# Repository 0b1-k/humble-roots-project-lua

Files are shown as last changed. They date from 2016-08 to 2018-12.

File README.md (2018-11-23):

**Summary**

The Humble Roots Project is a grow room automation control system designed for stable non-stop operation. It is managed through a single configuration file and can communicate with an administrator over SMS text messages. Data visualization is provided in the form of Grafana dashboards powered by InfluxDB.

**Dependencies**

Any platform capable of running Lua + sockets + file system support. Tested under Ubuntu 16, 17, 18+ and Raspbian.

***CMake***

```
sudo apt-get install cmake build-essential
```

***Git***

```
sudo apt-get install git
```

***LuaDist***

Install [LuaDist](http://luadist.org/) in the home folder.

***Humble Roots Project***

```
cd ~
git clone https://github.com/fabienroyer/humble-roots-project-lua.git
cd humble-roots-project-lua
cp -R * ~/LuaDist/share

# Compile the Serial Communication Library
cd ~/LuaDist/share/lua-serial
make

# Copy the library to the project folder. For 32-bit platforms:
cp ./build/lin32/libserial.so ~/LuaDist/share/weed
# or 64-bit platforms
cp ./build/lin64/libserial.so ~/LuaDist/share/weed

# Compile the SMS PDU encoding / decoding library
cd ~/LuaDist/share/smspdu
make

# Copy the library to the project folder. For 32-bit platforms
cp ./build/lin32/smspdu.so ~/LuaDist/share/weed
# or 64-bit platforms
cp ./build/lin64/smspdu.so ~/LuaDist/share/weed

# Copy the template config file to a usable .toml config file
cd ~/LuaDist/share/weed/config
mv config.tpl config.toml
cd ..
# Start the project
./../../bin/lua control.lua
```

On startup, the project will show a console output like this:

```
[TRACE 14:15:30] ./replay.lua:14: Replay data lines: 713
[INFO  14:15:30] control.lua:178: The Humble Roots Project
[INFO  14:15:30] control.lua:179: 
			                  |
			                 |.|
			                 |.|
			                |\./|
			                |\./|
			.               |\./|               .
			 \^.\          |\\.//|          /.^/
			  \--.|\       |\\.//|       /|.--/
			    \--.| \    |\\.//|    / |.--/
			     \---.|\    |\./|    /|.---/
			        \--.|\  |\./|  /|.--/
			           \ .\  |.|  /. /
			 _ -_^_^_^_-  \ \\ // /  -_^_^_^_- _
			   - -/_/_/- ^ ^  |  ^ ^ -\_\_\- -
					  	|

[INFO  14:15:30] control.lua:180: Copyright (c) 2017 Fabien Royer
[INFO  14:15:30] control.lua:185: Gateway started
[INFO  14:15:30] ./listener.lua:17: TCP listener @ ::1:42024
[DEBUG 14:15:31] control.lua:172: Replay node=2&rssi=-43&t=srh&bat=4.77&low=0&pwr=1&p=1
[DEBUG 14:15:32] control.lua:172: Replay node=20&rssi=-31&t=rly&bat=5.00&low=0&pwr=1&r=4&s=1
[DEBUG 14:15:33] control.lua:172: Replay node=20&rssi=-31&t=rly&bat=5.00&low=0&pwr=1&r=5&s=1
[DEBUG 14:15:34] control.lua:172: Replay node=20&rssi=-30&t=rly&bat=5.00&low=0&pwr=1&r=5&s=1
[DEBUG 14:15:35] control.lua:172: Replay node=40&rssi=-44&t=clm&bat=3.78&low=0&pwr=0&tmp=24.58&rh=55
...
```

***InfluxDB***

All sensor data is logged to [influxdb](https://influxdata.com/time-series-platform/influxdb/).
Once influxdb is installed, create a 'sensors' and an 'events' database, then enable influxdb logging in ./config/config.toml. See /weed/config/influxdb-udp.conf for a ready to use config snippet for communicating with InfluxDB over UDP (recommended over HTTP).

***Grafana***

Uses Grafana to plot sensor data. Once Grafana is installed, configure it to use the Influxdb instance previously installed and import the
Humble Roots Project dashboard from ./dashboard/grafana/Lab.json.

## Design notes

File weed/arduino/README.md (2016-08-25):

# Humble Roots Project Sketches

The various Arduino sketches provided as part of the project are intended to run on Moteino boards equipped with HopeRF RFM69W 433MHz transceivers.
The wireless nodes share a network ID but also have their own unique ID on the network.
In addition, the nodes encrypt all transmitted data using [AES-128](https://en.wikipedia.org/wiki/Advanced_Encryption_Standard).
To this end, the nodes must share a 16-byte long private key to be able to communicate with each other.
**By default, that private key is set to "&lt;YourCryptoKey!&gt;" which should be changed before compiling and uploading the sketches to the nodes.**
To do so, open the .ino files under the /arduino folder.
Then, using the 'Find...' (CTRL+F) function in the Arduino IDE, search for the default AES key and replace it with your own 16-byte long key.
Repeat this for each sketch, making sure to save all changes.

## Required Arduino Dependencies

The following libraries must be added to the Arduino IDE in order to compile the project sketches.

* [Si7021 temperature & humidity sensor library](https://github.com/LowPowerLab/SI7021)
* [BMP180 Bosch sensor library](https://github.com/LowPowerLab/SFE_BMP180)
* [RFM69 library for RFM69W and RFM69HW](https://github.com/LowPowerLab/RFM69)
* [Low Power Library for Arduino](https://github.com/LowPowerLab/LowPower)
* [PString text formating library](http://arduiniana.org/libraries/PString/)
* [EEPROMex arduino library](http://playground.arduino.cc/Code/EEPROMex)

# Bill of materials

The Arduino sketches provided with the Humble Root Project are designed to run on the following hardware or equivalent.

## Climate node

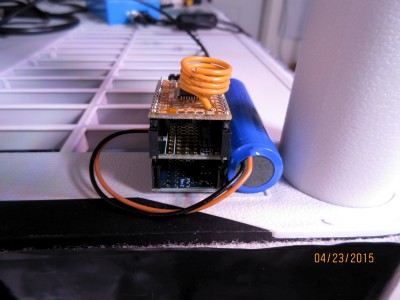
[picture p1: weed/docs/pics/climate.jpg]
Climate node


* 1x [Moteino MCU](https://lowpowerlab.com/shop/index.php?_route_=moteino-r4)
* 1x [Transceiver (RFM69W @ 433MHz)](https://lowpowerlab.com/shop/index.php?_route_=Moteino/RFM69W)
* 1x [Power Shield](https://lowpowerlab.com/shop/index.php?_route_=powershield)
* 1x [WeatherShield](https://lowpowerlab.com/shop/index.php?_route_=weathershield)
* 1x [Lithium Ion Cylindrical Battery - 3.7v 2200mAh](http://www.adafruit.com/products/1781)

## Gateway node

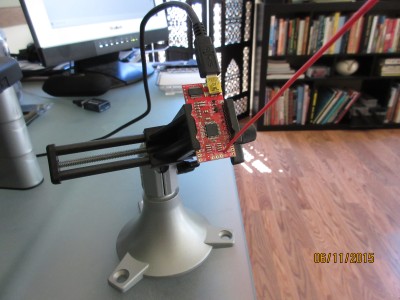
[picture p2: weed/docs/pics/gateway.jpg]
Gateway node


* 1x [Moteino USB MCU](https://lowpowerlab.com/shop/index.php?_route_=Moteino/moteinousb)
* 1x [Transceiver (RFM69W @ 433MHz)](https://lowpowerlab.com/shop/index.php?_route_=Moteino/RFM69W)
* 1x Mini USB cable
* 1x Computer capable of running Python 2.7.x

The Humble Roots Project Python code has been tested on the following systems

* [Ubuntu 14.04 (Desktop)](http://www.ubuntu.com/download/desktop)
* [Raspberry Pi (Debian Wheezy)](https://www.raspberrypi.org/downloads/)
* [BeagleBone Black (Ubuntu)](http://elinux.org/BeagleBoardUbuntu)

## Relay node

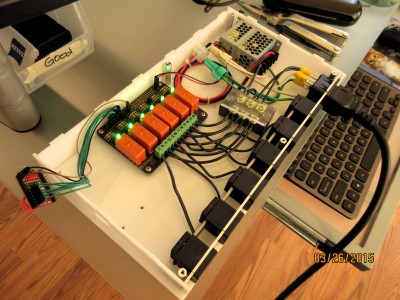
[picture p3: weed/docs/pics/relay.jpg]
Relay node


**Warning: the relay node switches high voltages and currents!**
**You must be comfortable working with high power before attempting to build this node.**
**Please seek help if you are unsure about the safety precautions needed when working with high power.**

* 1x [Moteino MCU](https://lowpowerlab.com/shop/index.php?_route_=moteino-r4)
* 1x [Transceiver (RFM69W @ 433MHz)](https://lowpowerlab.com/shop/index.php?_route_=Moteino/RFM69W)
* 1x [Humble Roots Project Relay Board](../hardware)
* 6x [Schurter AC Power Entry Modules SNAP-IN QC/WIRE NEMA](http://www.mouser.com/ProductDetail/Schurter/43000703/?qs=%2fha2pyFaduhBCtkGZdsCVlhWWizSnRMPw8sJ%2fGTwrMM%3d)
* 1x [Schurter AC Power Entry Modules 1.2mm Snap-In INLET 16A](http://www.mouser.com/ProductDetail/Schurter/47938000/?qs=%2fha2pyFaduhGWt2JM6mVJBsIsAazDcRYIle0WaEJEYg%3d)
* 1x [5V 15W 1 Phase Switching Power Supply](http://www.mouser.com/ProductDetail/Delta-Electronics/PMC-05V015W1AA/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)
* 1x [Schurter AC Power Cord IEC320 16A 2.0m V-Lock](http://www.mouser.com/ProductDetail/Schurter/60512047/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)
* 1x 12 AWG solid core wire spool (black)
* 1x 12 AWG solid core wire spool (green)
* 1x 12 AWG solid core wire spool (white)
* 1x 12 AWG stranded wire spool (black)
* 1x 12-10 AWG 6-Circuit Terminal Block
* 3x Winged Twist Wire Connectors
* 3x 12-10 AWG 0.25 in. Tab Female Fully-Insulated Disconnects
* 1x 24 AWG stranded prototyping wire (red)
* 1x 24 AWG stranded prototyping wire (black)

Note: any relay board with at least 6 channels capable of handling loads ranging from 10A to 16A @ 240V will work.

## Soil Relative Humidity Node

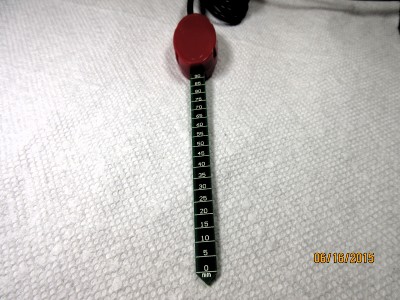
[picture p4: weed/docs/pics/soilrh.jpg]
Soil RH node


* 1x [Moteino MCU](https://lowpowerlab.com/shop/index.php?_route_=moteino-r4)
* 1x [Transceiver (RFM69W @ 433MHz)](https://lowpowerlab.com/shop/index.php?_route_=Moteino/RFM69W)
* 1x [MightyBoost](https://lowpowerlab.com/shop/index.php?_route_=mightyboost)
* 1x [Lithium Ion Battery Pack - 3.7V 6600mAh](http://www.adafruit.com/products/353)
* 1x [VH400 Soil Moisture Sensor Probe](http://www.vegetronix.com/Products/VH400/)

## Valve node

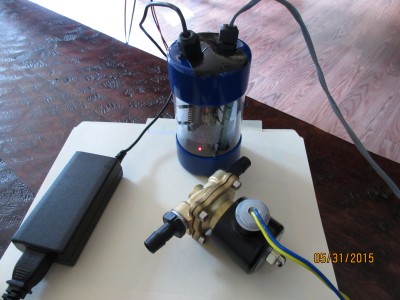
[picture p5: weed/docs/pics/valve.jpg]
Valve node


**Warning: the 'valve' node switches high currents!**
**You must be comfortable working with high power before attempting to build this node.**
**Please seek help if you are unsure about the safety precautions needed when working with high power.**

* 1x [Moteino MCU](https://lowpowerlab.com/shop/index.php?_route_=moteino-r4)
* 1x [Transceiver (RFM69W @ 433MHz)](https://lowpowerlab.com/shop/index.php?_route_=Moteino/RFM69W)
* 1x [Humble Roots Project Solenoid Control Board](../hardware)
* 1x [12V 5A Switching Power Supply](http://www.adafruit.com/product/352)
* 1x [Brass Liquid Solenoid Valve - 12V - 1/2 NPS](http://www.adafruit.com/products/996)
* 1x 18 AWG stranded wire (spool)

## Water Level nodes

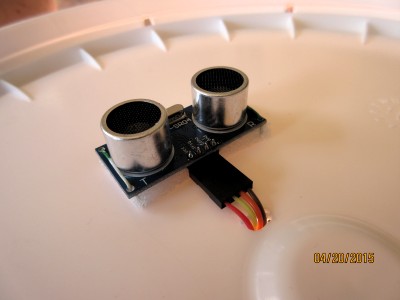
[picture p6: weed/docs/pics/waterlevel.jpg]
Water Level node


Two 'water level' nodes are used as part of the project as share the same code.
However, the network IDs for the two nodes are different and must be edited before compiling and uploading the code.

* A 'sump' node (ID=4)
* A 'tank' node (ID=30)

Start by loading the [waterlevel.ino sketch](./waterlevel/waterlevel.ino) in the Arduino IDE.

Locate the following line, ensuring that the node ID is set to 4.

```
	#define THIS_NODE_ID             4
```

Compile the sketch and upload it to the Moteino node used for the 'sump' node.

Then, set the node ID to 30.

```
	#define THIS_NODE_ID             30
```

Compile the sketch again and upload it to the Moteino node used for the 'tank' node.

* 1x [Moteino MCU](https://lowpowerlab.com/shop/index.php?_route_=moteino-r4)
* 1x [Transceiver (RFM69W @ 433MHz)](https://lowpowerlab.com/shop/index.php?_route_=Moteino/RFM69W)
* 1x [HC-SR04 ultrasonic sensor](https://lowpowerlab.com/shop/index.php?_route_=HC-SR04)
* 1x [SparkFun micro B USB Breakout](https://www.sparkfun.com/products/12035)
* 1x [5V 1A (1000mA) USB port power supply](http://www.adafruit.com/products/501)
* 1x Micro B USB cable

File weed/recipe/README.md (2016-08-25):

Recipe intended to grow Indica plants with a 45 days flowering cycle.

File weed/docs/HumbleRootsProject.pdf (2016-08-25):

# The Humble Roots Project

## Home Automation Applied To Medical Cannabis Cultivation

Author: Fabien Royer (https://www.linkedin.com/in/fabienroyer1967)

Copyright (c) 2015 Fabien Royer (https://www.linkedin.com/in/fabienroyer1967)

Source: https://github.com/fabienroyer/humble-roots

License: Attribution-ShareAlike 4.0 International (CC BY-SA 4.0) (https://creativecommons.org/licenses/by-sa/4.0/)

## Table of Contents

## Introduction

The Humble Roots Project is a grow room automation system designed to meet indoor horticulture challenges using open (http://www.gnu.org/)software, (http://www.gnu.org/) open hardware (https://en.wikipedia.org/wiki/Open-source_hardware) and readily available consumer appliances. The project blends these elements together into an inexpensive, reliable, efficient, automated system, with a focus on sustainability. (https://en.wikipedia.org/?title=Sustainability)
The application of the concepts and technology used as part of the Humble Roots Project is not limited to indoor growing or horticulture; it has far-reaching applications to many other automation scenarios where sensors, actuators, rules and data visualization are combined to solve a problem.

## Inspiration

In 2013, the Humble Roots Project was born out of a need to grow medical cannabis indoors legally, (http://www.doh.wa.gov/ForPublicHealthandHealthcareProviders/HealthcareProfessionsandFacilities/MedicalMarijuanaCannabis) using sustainable, organic, pesticide-free (http://agr.wa.gov/FP/Pubs/docs/398-WSDACriteriaForPesticideUseOnMarijuana.pdf) cultivation methods capable of producing consistent yields, in both quality and quantity.
Medical cannabis patients and caretakers who have determined that investing in their own garden is financially sound and healthy still face several challenges: cannabis can be tricky to grow, (http://www.seattletimes.com/seattle-news/for-pot-yield-of-growersrsquo-dreams-fickle-plants-need-constant-care/) requires constant care and a well-controlled climate (http://blogs.seattletimes.com/pot/2014/08/18/from-seed-to-sale-challenges-abound-for-licensed-pot-growers/) in order to thrive.
While commercial greenhouse automation controllers are well-suited for this task, they're also expensive, proprietary, closed source solutions. Small scale growers typically resort to using 'low-tech' or 'no tech' solutions (i.e lights and irrigation on timers, climate control using a basic thermostat and humidistat) at the risk of losing entire crops. (http://www.growweedeasy.com/7-step-remedy)
The Humble Roots Project was built to fill the gap between commercially available automation systems and low-tech solutions. By automating the control of key processes, and by following some basic best practices, the Humble Roots Project empowers gardeners with the knowledge and the tools needed to reduce certain classes of risks, to minimize manual labor and to conserve precious resources, such as water and power.
To mitigate the steep learning curve associated with cannabis cultivation, the Humble Roots Project aims to provide recipes for growing different types of plants. A recipe is a complete plan for managing the growth cycle of a plant from seed/clone to harvest, including variables such as watering and feeding schedules, lighting schedule, temperature and humidity control, among others. The recipes are meant to educate and guide the budding gardener, as well as allowing a master grower to experiment with and fine-tune the quality and consistency of her yields.

## Indoor Growing Basics

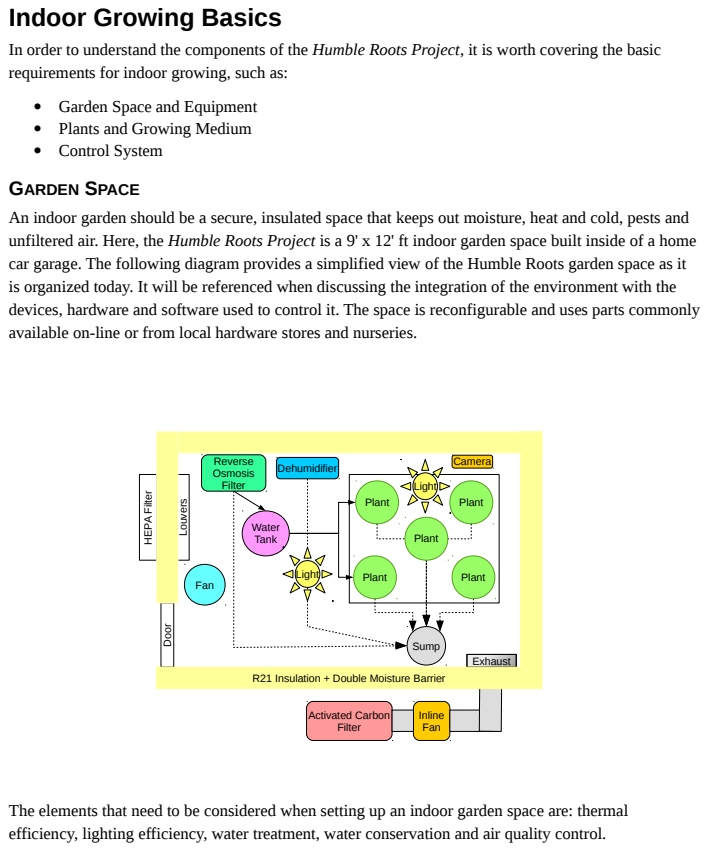
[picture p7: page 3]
Door; HEPA Filter; Louvers; Activated Carbon Filter; Inline Fan; Exhaust; Plant; Sump; Water Tank; Reverse Osmosis Filter; Fan; Light; Dehumidifier

In order to understand the components of the Humble Roots Project, it is worth covering the basic
requirements for indoor growing, such as:
• Garden Space and Equipment
• Plants and Growing Medium
• Control System

GARDEN SPACE
An indoor garden should be a secure, insulated space that keeps out moisture, heat and cold, pests and
unfiltered air. Here, the Humble Roots Project is a 9' x 12' ft indoor garden space built inside of a home
car garage. The following diagram provides a simplified view of the Humble Roots garden space as it
is organized today. It will be referenced when discussing the integration of the environment with the
devices, hardware and software used to control it. The space is reconfigurable and uses parts commonly
available on-line or from local hardware stores and nurseries.

R21 insulation & double moisture barriers

Camera

R21 Insulation + Double Moisture Barrier

The elements that need to be considered when setting up an indoor garden space are: thermal
efficiency, lighting efficiency, water treatment, water conservation and air quality control.

Thermal Efficiency
When designing an indoor garden, it is important to make sure the room

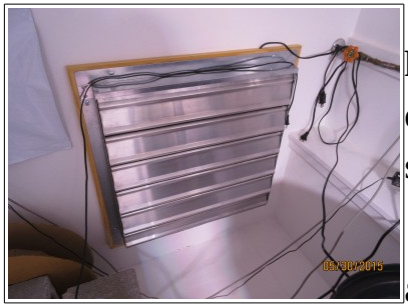
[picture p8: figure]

has high thermal efficiency. Thermal efficiency is important because it has a direct impact on the resources dedicated to heating and cooling the garden space.
For the Humble Roots Project, the garden is located in a room elevated above ground to prevent the floor from getting too cold during the winter months. The floor, the walls and the ceiling are filled with R21 insulation material. (http://energy.gov/energysaver/articles/tips-insulation) The insulated material is sandwiched between two plastic moisture barriers. The door is made of metal, can be locked and seals tightly with its frame.
Because the room is well insulated, it allows for semi-passive cooling and saves a great deal of energy in the process since an air conditioning unit is not required.
Passive cooling relies on a temperature differential between cool outside air and warm air inside of the room. A fan draws cool air inside the room while exhausting warm air.
Running the system at night, when lights are on, ensures that the temperature difference between the two zones is adequate for passive cooling. It also makes operating the garden cheaper since the cost of grid power drops dramatically during off-peak hours.
Louvers automatically lift when air enters the space and shut themselves off afterward, preventing light, air and smells from leaking in or out of the garden. This makes the room ideal for growing and curing cannabis after harvesting. We will see later how software contributes to achieving a climate equilibrium and further contributes to saving energy.

Lighting Efficiency
The largest power consumer in an indoor garden is the lighting. For that

reason, it is important to ensure that it is as efficient as possible: as much light as possible needs to be usable by the plants while keeping the amount of heat produced by the light down to a minimum.
The Humble Roots Project uses two LED lamps, totaling 885 Watts, to illuminate the ~4.5' x 4.5' planted area from above and from one side. The room is painted flat white, from floor to ceiling, making for a very bright environment, maximizing the lamps' output.
LED lights were chosen for their efficiency: they're engineered to only emit light in the blue, red, IR and Ultraviolet (A) parts of the spectrum, which plants thrive on. Nearly all of the green portion of the spectrum is eliminated as it is useless for photosynthesis and therefore, saves energy. These lamps produce little heat, which makes passive cooling possible.
The power of the lamps is sufficient to penetrate through canopy foliage and promotes heavier growth even in the lower parts of the plants.
Finally, LED lamps do not require electronic ballasts, further reducing heat, wiring complexity and potential failure points. Efficiency and reduced part count both help offset the higher cost of LED lamps compared to other lamp types.

Water Treatment and Conservation
Water management in an indoor garden is often the most problematic

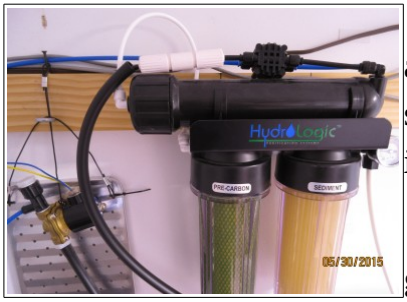
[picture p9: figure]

aspect that needs to be addressed: first, cannabis plants are particularly sensitive to water quality. Second, managing water indoors can be a labor intensive task if there's no infrastructure in place to ease the process.
In the Humble Roots Project, a copper pipe brings cold city water into the garden space. Another PVC pipe leading to the sewers is used to drain out the gray water out of a sump.
City water quality varies greatly depending on where you live but even good quality city water invariably contains additives, such as Chlorine or Chloramine (http://en.wikipedia.org/wiki/Chloramine) as well as other minerals that will negatively impact cannabis plants. If left unfiltered, these minerals and metals can lead to toxicity or deficiencies in the plants. Therefore, it is wise to 'scrub' city water with a carbon filter or a reverse-osmosis system before using it in a cannabis garden.

There are efficiency trade-offs to be considered with different water treatment methods: for instance, a reverse-osmosis system produces some 'waste water' and carbon filters eventually need to be replaced.
While Chlorine just evaporates when left to air out for a few days, Chloramine takes much longer to dissipate and that water can be problematic to store in the meantime and can add unwanted humidity to the air.
Carbon filtering and reverse-osmosis have both been used successfully as part of this project. The operation of the reverse-osmosis system is controlled through a solenoid valve and an ultrasonic distance sensor monitoring the water level in a holding tank.
Assuming that water has been properly conditioned, it still must be applied with care: too much water will prevent the root system from accessing oxygen, stunting and eventually killing the plant. Too little water and the plant will starve, dry out and die too. Accurately tracking and maintaining an optimal moisture level in the growing medium is not only beneficial to the plants, it is also beneficial to our drought-stricken environment: by using smart irrigation techniques, one can grow a very healthy patch of plants with less water per day than is required to flush an average toilet just once. A custom irrigation system was built to meet this goal, combining a soil moisture probe buried root-deep in one of the pots with a water distribution 'network' going to each plant. Software determines when to irrigate and how much.

Some growing techniques consume larger amounts of water than others: for instance, growing with a hydroponic system, except Aeroponics, (https://en.wikipedia.org/wiki/Aeroponics) requires far more water than growing in soil, regardless of scale. For this reason, the Humble Roots Project favors soil as its growing medium. A good soil mix retains just the right amount of moisture, is well oxygenated and provides a strong buffer against sudden pH fluctuations. Soil can also be re-used when cared for and amended properly.

The run-off water coming from irrigating the plants, from the reverse-osmosis system and from the dehumidifier drain into a 'sump', made from three 5-gallon buckets linked together. When the water reaches a defined level, as measured by an ultrasonic distance sensor, it is automatically pumped out to the sewers.

Once combined with nutrients, the pH balance of the water is extremely important to test and adjust, regardless of the growing medium: it affects the availability of nutrients (https://planetpermaculture.wordpress.com/2013/07/25/ph-chart-showing-nutrient-availability/) to the plants and the plants' ability to uptake water. This is addressed in the grow recipes driving the automation. It also ensures that the run-off water pumped out to the sewers is as close to being pH neutral and as nutrient-free as possible.

Air Treatment
Maintaining excellent air quality is vital to grow a healthy garden: filtering out contaminants such as spores, pollens, dust, mites, is key to preventing a host of problems that can quickly destroy a crop. For that reason, in the Humble Roots Project, all the air entering the garden is filtered through a MERV 12 (http://en.wikipedia.org/wiki/Minimum_efficiency_reporting_value) box filter.
Similarly, it is also critical to maintain
an optimal range for air temperature,
relative humidity and CO2 levels, as they also impact the growth of the plants and the amount of resin produced by cannabis flowers.
Air temperature within the grow room is controlled by a powerful
in-line fan exhausting hot air through an activated carbon filter,
scrubbing the air and removing odors in the process. Note that the
filter is mounted outside of the room: this is slightly less efficient than mounting the carbon filter on the inside, but the gain in space is worth the small efficiency trade-off in this case.

A constant air flow is maintained within the room, thanks to a fan circulating

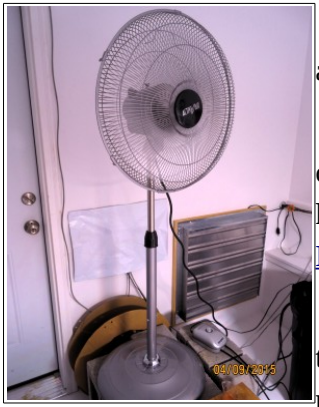
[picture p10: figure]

air around the plants.
The relative humidity within the room is
controlled through a small dehumidifier unit,
keeping molds, such as Powdery Mildew (http://en.wikipedia.org/wiki/Powdery_mildew) and Botrytis, (http://edrosenthal.com/2012/08/ask-ed-marijuana-grow-tip-44-the-botrytis-solution.html) from being able to develop. Controlling air moisture levels also improves

the performance of the activated carbon filter by
preventing carbon particles from 'clumping'
together when excessively humid air passes through it. It's worth mentioning that relative humidity sensors built into consumer-

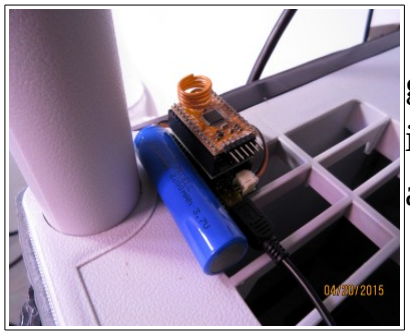
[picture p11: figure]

grade appliances often lack in accuracy. The Humble Roots Project takes this issue into account by using precise sensors so that inexpensive consumer appliances can be controlled accurately.

PLANTS AND GROWING MEDIUM
To make the most of the light available to them, each plant is potted in

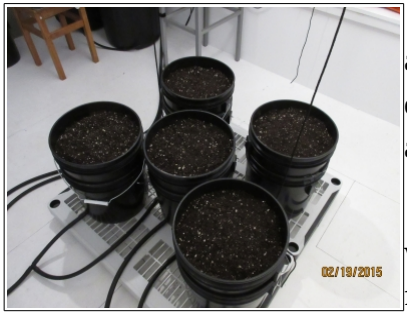
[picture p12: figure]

a 3.5 gallon bucket, allowing for a healthy root system and foliage to develop but not so large that competition for light resources becomes an issue.
A screen mesh helps with training the plants to grow uniformly wherever light is available and helps support the stems during the flowering phase of the growth. The 'planter buckets' are inserted in water collection buckets, all leading to a sump through gravity and flexible tubing.

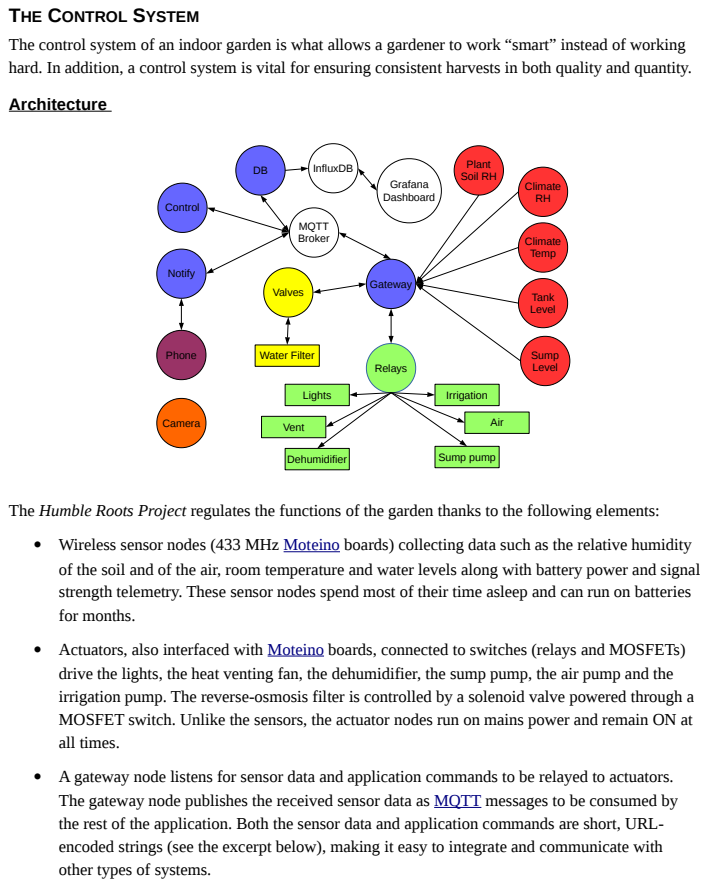
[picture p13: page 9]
Architecture; MQTT Broker; Control; Notify; Gateway; Plant Soil RH; Sump Level; Camera; Relays; Tank Level; Climate RH; Climate Temp; InfluxDB; Grafana Dashboard; Lights; Vent; Dehumidifier; Sump pump; Air; Irrigation; Phone; Valves; Water Filter

THE CONTROL SYSTEM
The control system of an indoor garden is what allows a gardener to work “smart” instead of working
hard. In addition, a control system is vital for ensuring consistent harvests in both quality and quantity.

The Humble Roots Project regulates the functions of the garden thanks to the following elements:
• Wireless sensor nodes (433 MHz Moteino (https://lowpowerlab.com/shop/index.php?_route_=Moteino) boards) collecting data such as the relative humidity
of the soil and of the air, room temperature and water levels along with battery power and signal
strength telemetry. These sensor nodes spend most of their time asleep and can run on batteries
for months.
• Actuators, also interfaced with Moteino (https://lowpowerlab.com/shop/index.php?_route_=Moteino) boards, connected to switches (relays and MOSFETs)
drive the lights, the heat venting fan, the dehumidifier, the sump pump, the air pump and the
irrigation pump. The reverse-osmosis filter is controlled by a solenoid valve powered through a
MOSFET switch. Unlike the sensors, the actuator nodes run on mains power and remain ON at
all times.
• A gateway node listens for sensor data and application commands to be relayed to actuators.
The gateway node publishes the received sensor data as MQTT (http://mqtt.org/) messages to be consumed by
the rest of the application. Both the sensor data and application commands are short, URL-
encoded strings (see the excerpt below), making it easy to integrate and communicate with
other types of systems.

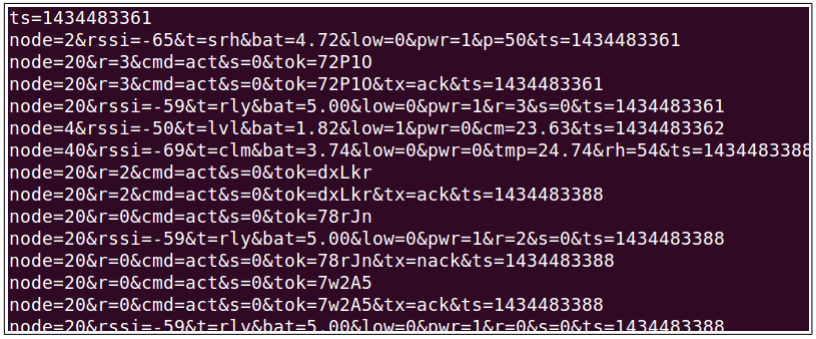
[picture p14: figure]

- Independent application processes (Gateway, DB, Control and Notify) subscribe to sensor data messages and react to them. The Gateway process interfaces with the gateway node over a serial port and therefore, must run on the same physical machine. The other processes can be distributed to separate machines as needed. The DB process writes to a time-series database (InfluxDB) (http://influxdb.com/) feeding Grafana (http://grafana.org/) dashboards; the Control process compares sensor data messages against a user-defined rule set and determines what commands need to be issued to actuators or to other application processes. It also manages time-based rules and configuration changes and last, but not least, executes growth recipes. The Notify process listens for push notifications, (https://www.pushbullet.com/) such as IFTTT commands (https://ifttt.com/recipes) originating from mobile devices. It also pushes notifications back to mobile devices: for instance, Notify can respond to an alert raised by the Control process by sending an SMS message or it can forward a status report whenever requested, among other scenarios. The processes are written in Python (https://www.python.org/) (2.7.x) to maximize portability and will run fine even on a resource-constrained 1st generation Raspberry Pi. (https://www.raspberrypi.org/)
- The Camera process takes pictures of the garden every hour and serves them over HTTP. The hardware used for that purpose is a Raspberry Pi equipped with a camera module, but anything else can be used. The images are meant to observe the impact of recipe changes over time and to produce fun plant growth time lapses. (https://www.youtube.com/watch?v=OL0RneAysnU)

Python, MQTT, Arduino and life at 433 MHz
These technologies were chosen for a simple reason: they're inexpensive, open, well documented and capable of running just about anywhere without being bound to a specific vendor platform: considering the constant stream of development boards coming on the market, it seemed wise for this project to abstract the underlying hardware and the operating system as much as possible. Python, MQTT and Arduino all support this goal.
The choice of using 433 MHz radios from HopeRF deserves a more in-depth explanation: the application doesn't care what the underlying communication link is and from that standpoint, WiFi and Bluetooth would work equally well. For instance, you could mix and match or swap out the Moteino (http://lowpowerlab.com/moteino/) nodes for Particle (https://www.particle.io/) cores, LightBlue (https://punchthrough.com/bean/) beans, AirBoards (http://www.theairboard.cc/) or any other flavor of 'IoT' (http://en.wikipedia.org/wiki/Internet_of_Things) board without the rest of the application knowing about it.

However, in this instance, using HopeRF RFM69x 433 MHz (http://www.hoperf.cn/upload/rf/RFM69-V1.3.pdf) radios had several benefits over the alternatives: because they operate at a lower frequency, these radios work well against obstacles while consuming very little power during transmissions (16mA to 45mA) and can be put to sleep to conserve power. Yet, they maintain a very good range, appropriate for indoor and outdoor applications on our 'homestead'. WiFi alternatives consumed too much power (~150mA) to be viable for extended battery-powered scenarios. Bluetooth Low Energy (http://en.wikipedia.org/wiki/Bluetooth_low_energy) sips power just like the RFM69x radios, but it operates at 2.4 GHz which doesn't work well in point-to-point topologies with no line of sight between transceivers. Since cost was a concern, deploying a mesh network to work around obstacles was out of the question, even though the HopeRF radios can be configured to work in a mesh topology if necessary. ZigBee, (https://en.wikipedia.org/wiki/ZigBee) Xbee, and Z-Wave (https://en.wikipedia.org/wiki/Z-Wave) transceivers were disqualified for the same reasons as the Bluetooth LE option and the HopeRF radios emerged as the best wireless solution given the constraints of this project.

Hardware
Sensors
To make the Humble Roots Project as easy as possible for others to reproduce, readily available hardware sensors were used (see the Project Repository (https://github.com/fabienroyer/humble-roots) for the bill of materials). The criteria for selecting the sensors were: precision, reliability, durability, availability and cost.
Measuring Relative Soil Humidity
Because all the plants have the same genetics, the same age, use the

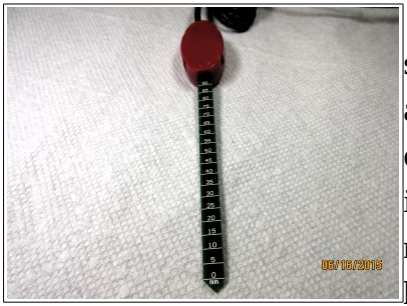
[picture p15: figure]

same soil mix, are planted in identically-sized pots and receive the same amount of light, they tend to behave in the same way as far as water consumption goes. Therefore, one analog capacitive soil moisture probe (http://www.vegetronix.com/Products/VH400/) is used to measure the relative humidity of the soil within a single pot representative of the rest of the plants, which substantially reduces hardware costs and complexity.
The probe used by the project is a closed hardware sensor unfortunately

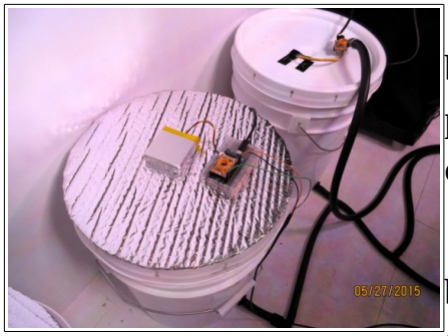
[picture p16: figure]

but it has key advantages over several open hardware alternatives: the probe responds extremely fast to relative humidity changes and cannot corrode in the soil since there's no exposed metal parts.
Most importantly, the probe is thin and entirely waterproof and can be buried deep into the soil where the plant's root ball is densest. Burying the probe well below the soil's surface provides excellent visibility into the actual relative humidity of the soil and in return, ensures that the irrigation system can be controlled accurately. The probe and the wireless Moteino node reading it are both powered via a MightyBoost (https://lowpowerlab.com/shop/index.php?_route_=all-products/mightyboost) power supply backed by a Li-Po battery.

Measuring Relative Air Humidity and Temperature As mentioned above, the relative humidity of the air as well as the

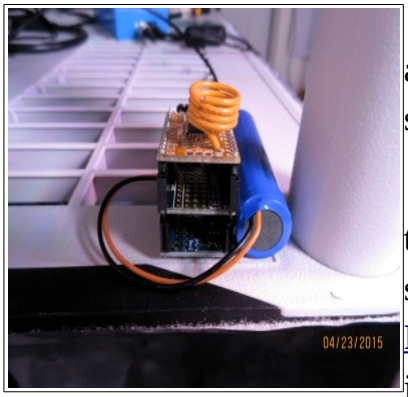
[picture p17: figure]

ambient temperature must be controlled accurately to prevent potentially serious problems from developing in the grow room.
To this end, a Moteino WeatherShield (https://lowpowerlab.com/shop/index.php?_route_=weathershield) featuring an I2C Si7021 (http://www.mouser.com/ds/2/368/Si7021-A20-519770.pdf) temperature & humidity sensor as well as a BMP180 (http://www.bosch-sensortec.com/en/homepage/products_3/environmental_sensors_1/bmp180_1/bmp180) atmospheric pressure sensor were used to measure air quality. The node is powered by a PowerShield (https://lowpowerlab.com/shop/index.php?_route_=powershield) supply also backed by a Li-Po battery. The temperature data is used to drive the vent fan while the relative humidity data drives the dehumidifier.
Measuring Water Levels
In order to determine the level of water in the sump and water holding

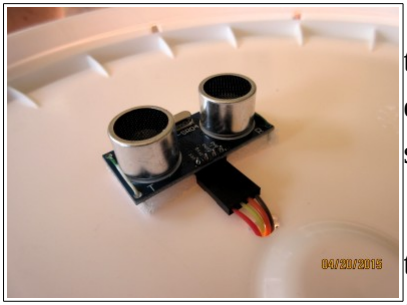
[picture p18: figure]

tanks, inexpensive, yet accurate HC-SR04 (https://lowpowerlab.com/shop/index.php?_route_=HC-SR04) ultrsonic (https://lowpowerlab.com/shop/index.php?_route_=HC-SR04) sensors (https://lowpowerlab.com/shop/index.php?_route_=HC-SR04) are used to evaluate the distance between the surface of the water and the sensor: the shorter the distance returned by the sensor, the higher the water level. For the sump, a rule determines when the water level requires activating the pump draining the water to the sewers. For the water holding tank, another rule determines if the solenoid valve controlling the reverse-osmosis filter should be activated. In both cases, the sensors are powered through 5V phone charger supplies feeding the sensors and the Moteino nodes. They will eventually make use of Li-Po backed power supplies as well.
Actuators
For the actuator nodes, a couple of custom devices needed to be created: when the project started, suitable alternatives were unavailable at affordable prices or had inadequate power specifications for the tasks at hand. Now that countless 'IoT' devices have flooded the market, it may be possible to substitute these custom devices with 'off the shelf' solutions and some software integration work but for the time being, that topic is out of scope.
The Relay Switch Box
The 'relay switch box' can control six different appliances, which can be

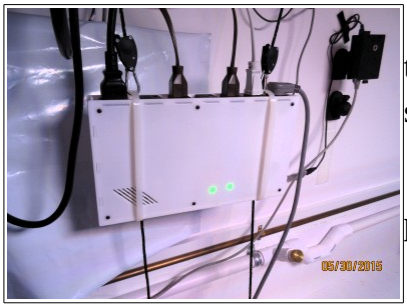
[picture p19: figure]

turned ON or OFF through mechanical relays, up to 16A @ 240V. A single power cord connects the mains to the switch box.
On the inside, a 5V power supply is used to energize the relays and powers the Moteino node driving their operation.
This switch box was initially controlled through a custom 'I2C over Ethernet' interface for which the Moteino node was a simple drop-in replacement, leaving some extra space and holes in the case.

Panel-mount outlets are supported by a custom laser-cut aluminum

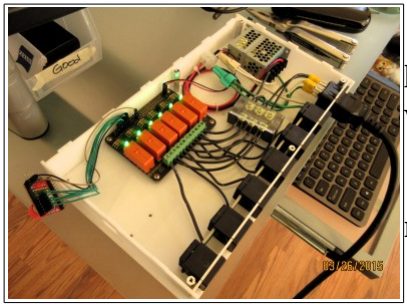
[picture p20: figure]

plate, ensuring that the case is sturdy and can handle the force applied when inserting and removing power plugs.
The switch box case is made of flat white laser-cut acrylic, which maximizes the amount of light reflected toward the plants.

The Valve Switch Box
To ease working with solenoids, a custom board was designed, capable of

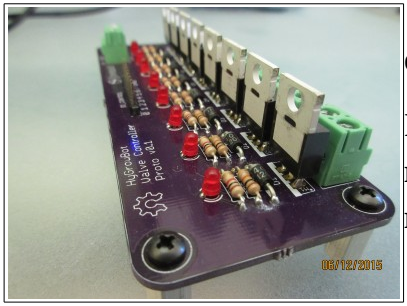
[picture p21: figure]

driving eight N-Channel Power MOSFETs. (https://en.wikipedia.org/wiki/MOSFET)
In the context of this project, a single 12V / 3A solenoid valve is needed to manage the reverse-osmosis water filter, making for simple power requirements and eliminating the need for heat sinks on the MOSFETs.
A recycled 12V / 5A laptop power supply turned out to be ideal for powering the solenoid and the micro-controller at the same time since the

voltage regulator on the Moteino board accepts DC inputs up to 16 volts. A single 470uF electrolytic capacitor decouples the Moteino controller from its power supply, preventing brownout-induced resets whenever a solenoid is energized.
Note: LEDs emitting colors other than green should never be used in a grow room to avoid interfering with the light cycle of the plants whenever

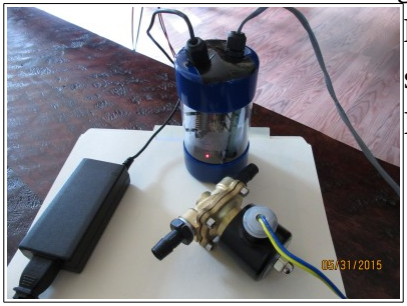
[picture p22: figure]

lights are turned off. Any non-green LED visible during dark periods should be covered with black electrical tape or should be replaced with LEDs that emit true green light instead.

## Recipe-Driven Automation Rules

All automation operations in the project are driven through a set of rules generated from plant growth models called 'recipes'. A recipe breaks down the growth cycle into time periods of varying durations. For each day within a specific period of time, the recipe provides all the relevant parameters driving the climate control system, the irrigation, the light cycles as well as the exact feeding schedule for the plants. Some of these parameters are used as automation rules while others are directed to the gardener via notifications about what needs to be done on a given day. The interface used to create the recipes is a simple spreadsheet at the moment but a mobile application is in the works.

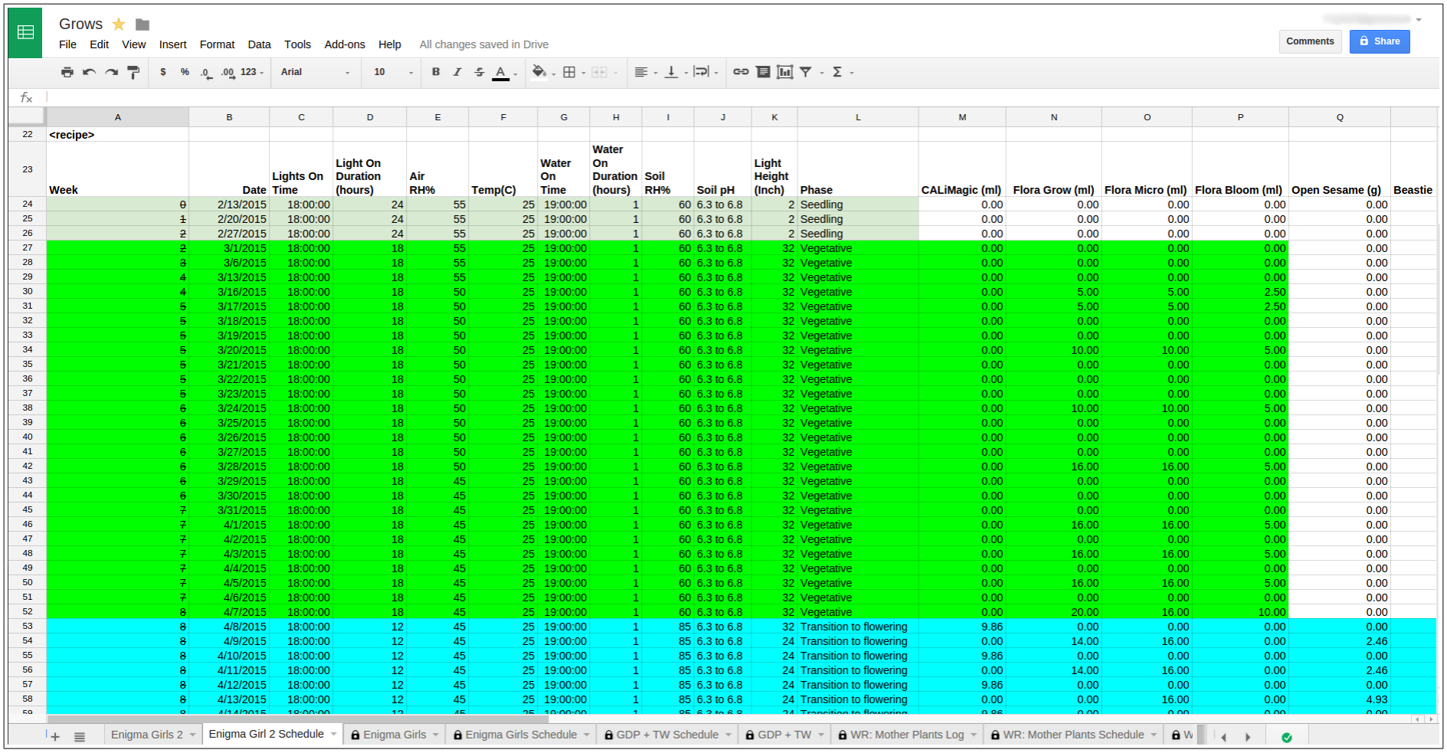
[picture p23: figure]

The parameters defined by the recipe result in JSON (http://json.org/) rules driving the automation and alerts.

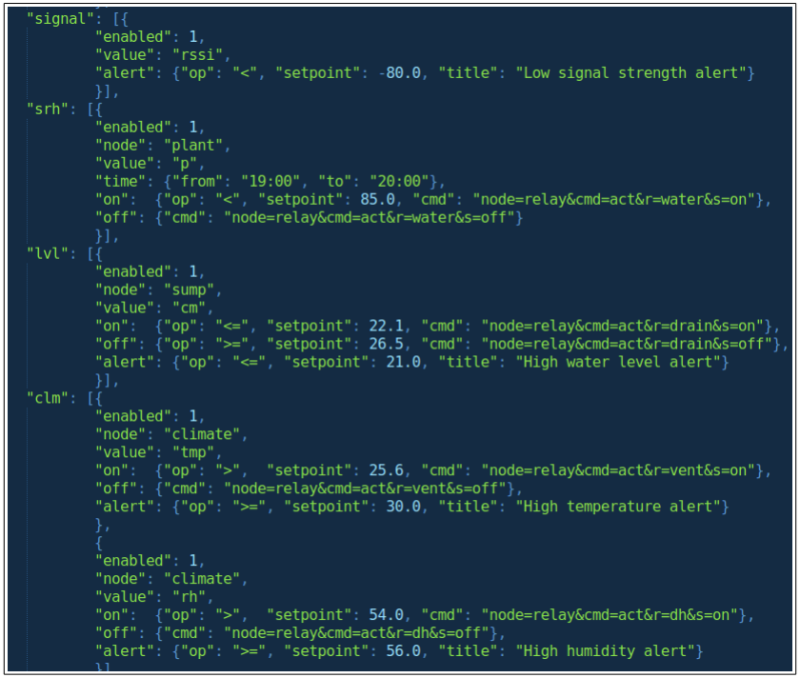
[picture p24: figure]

## Dashboards

Collecting long-term data provides several benefits for gardeners such as real-time monitoring of the climate and systems operating the grow room, ongoing analysis of energy efficiency, tuning growth recipes to improve yields from harvest to harvest are some of the most common applications.
Being able to 'rewind' time is also invaluable for troubleshooting purposes: the context provided by the data not only eliminates guesswork, it enables peer reviews and allows for the discovery of patterns that could otherwise be difficult to detect.
The screen shots below provide sample views being used in the project to monitor the behavior of the grow room over various time frames.


Climate – 12 Hour View

Climate – 30 Day View


Soil Relative Humidity – 12 Hour View

Soil Relative Humidity – 30 Day View


Sump Depth Level – 12 Hour View

Sump Depth Level – 30 Day View

Node Signal Strength – 12 Hour View


Node Signal Strength – 30 Day View


## Conclusion

As of June 2015, the Humble Roots Project has been a living experiment for the past 2.5 years. It has gone through several iterations of hardware and software, incrementally reducing complexity along the way.
With each iteration of the project, a new crop of medical cannabis was successfully grown, enabling recipes to be crafted for the following strains: White Rhino, (https://www.leafly.com/indica/white-rhino) Dr. Who, (https://www.leafly.com/hybrid/dr-who) Trainwreck, (https://www.leafly.com/hybrid/trainwreck) Grand Daddy Purple (https://www.leafly.com/indica/granddaddy-purple) and two other hybrid (https://www.leafly.com/news/cannabis-101/sativa-indica-and-hybrid-whats-the-difference-between-cannabis-ty)Indica (https://www.leafly.com/news/cannabis-101/sativa-indica-and-hybrid-whats-the-difference-between-cannabis-ty) strains dubbed Enigma Girls due to their unknown origins. This last point is important: modeling plant growth into recipes works well and is repeatable given similar genetics. Finally, thanks to commonly available sensors, some 'home automation' components, and following simple horticultural best practices, it is possible to build a well-controlled indoor garden, ideally suited for producing high-quality cannabis, sustainably, every time.
Hopefully, the Humble Roots Project will inspire others in the medical cannabis community to participate in crafting and sharing recipes for their favorite strains...

## Project Repository

https://github.com/fabienroyer/Humble-Roots-Project

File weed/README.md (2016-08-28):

# The Humble Roots Project (v1.0)
**Home Automation Applied To Medical Cannabis Cultivation**

The *Humble Roots Project* is a grow room automation system designed to meet indoor cannabis horticulture
challenges using open software, open hardware and readily available consumer appliances. The project
blends these elements together into an inexpensive, reliable, automated system, with a focus
on sustainability.

For in-depth details about the project, check out the [project documentation](./docs/HumbleRootsProject.pdf).

This version of the project is a complete Lua re-write of the former Python codebase.
Lua was found to provide greater reliability for long-running processes. It also takes far less resources than the 
Python implementation and is ideal on low-power systems such as the Raspberry Pi.
This implementation is single-threaded to prevent potential deadlocks and race-conditions.

Humble Roots Lab

**Plant Growth Timelapse**

<a href="http://www.youtube.com/watch?feature=player_embedded&v=OL0RneAysnU
" target="_blank">Enigma Girls 2 Growth Timelapse</a>

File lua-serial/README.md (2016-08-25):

ul_serial
=========

Lua serial port library

Donate: ** Paypal edartuz@gmail.com **

Serial port communication functions for Lua.
For timing functions requires function os.delay_us(us) (in ul_time module).
  
* Compilation with gcc (Linux) or MinGW-gcc (Windows):
  * `make`
* Cross-compilation in Linux:
  * 32-bit target: `make COMSPEC=command`
  * 64-bit target: `make COMSPEC=command PROCESSOR_ARCHITECTURE=AMD64 CPU=k8`
  
## Examples:
* Get list of available ports: `ports = io.Serial:getPorts()`
* After calling getPorts() list of system ports stored to io.Serial.ports variable: `ports = io.Serial.ports`
* Open port and set parameters. Port can be port's name or number (starting at 1):
  * `p = io.Serial{port='/dev/ttyUSB0', baud=9600,bits=8,stops=0,parity='n'}`
  * or `p = io.Serial:open{5}:baud(1200):bits(8):stops(2):parity('e'):DTR(0):RTS(1)`
* Set parameters:
  * `p:config{baud=1200,bits=8,stops=2,parity='e',DTR=0,RTS=1}`
  * or using method chaining: `p:baud(1200):bits(8):stops(2):parity('e'):DTR(0):RTS(1)`
* Get number of bytes waiting in receive buffer: `n = p:available()`
* Read all received data (as string): `p:read()`
* Wait for reception of at least 64 bytes, with 100ms timeout, receive data on success:
```lua
    to = p:waitRX(64, 100)
    if to == 0 then
    	print('Timeout occured...')
	else
		data = p:read()
	end
```
* Transmit string of bytes: `p:write(string)`
* Wait all data to send: `p:drainTX()` or `p:waitTX()`
* Close port: `p:close()`

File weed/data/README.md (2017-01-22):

**InfluxDB database backups**

Each .zip file in this folder contains a complete influxDB database snapshot with sensor and
event data as they were recorded during a grow cycle. The filename corresponds the strain grown during that cycle.

For instructions on how to restore this data to your own
influxDB instance, see 
this [page](https://docs.influxdata.com/influxdb/v1.1/administration/backup_and_restore/).

Once restored, you can explore the data through [Grafana](http://grafana.org/) 
using the dashboards provided under /dashboard/grafana.

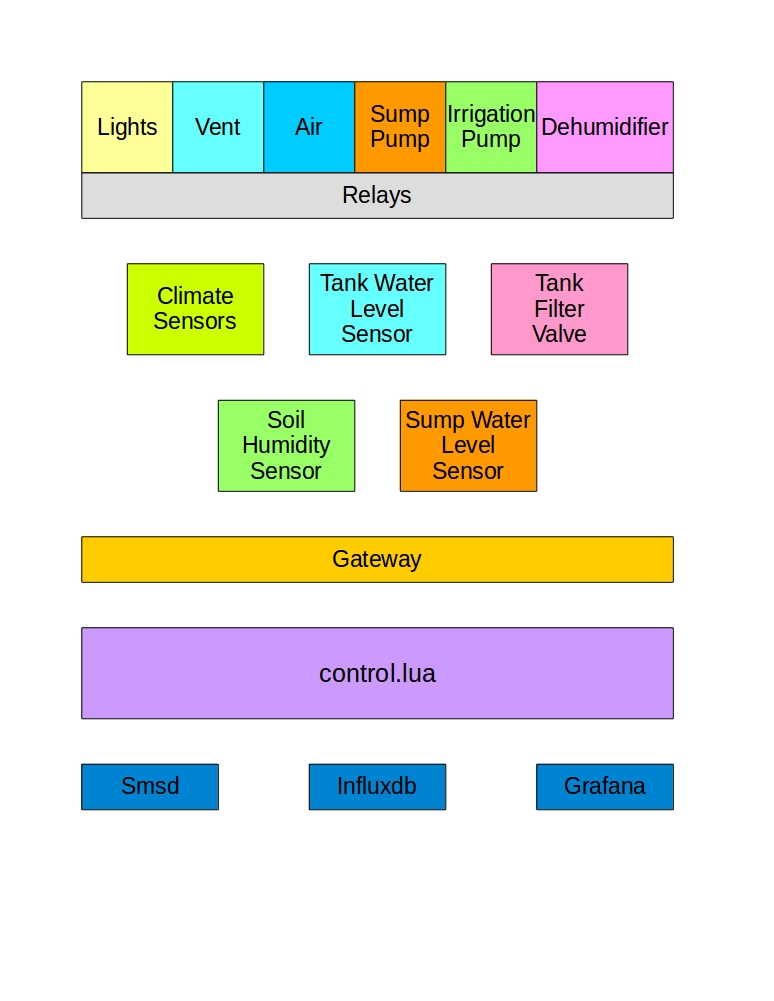
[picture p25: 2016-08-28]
weed/docs/Architecture.jpg

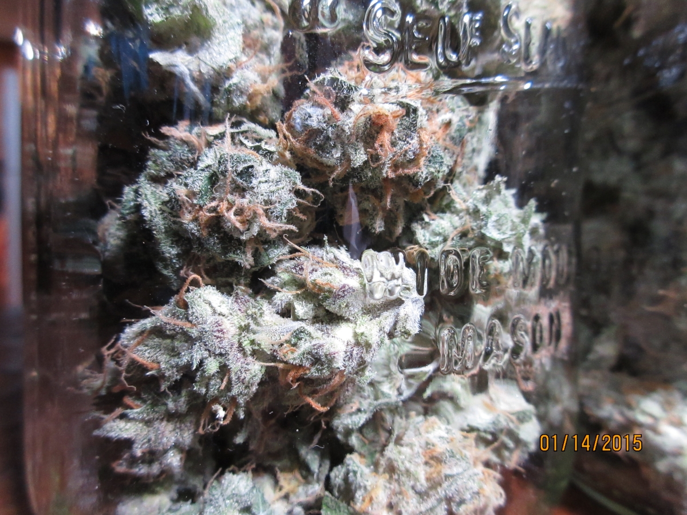
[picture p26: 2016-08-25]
weed/pics/EG2.2.jpg

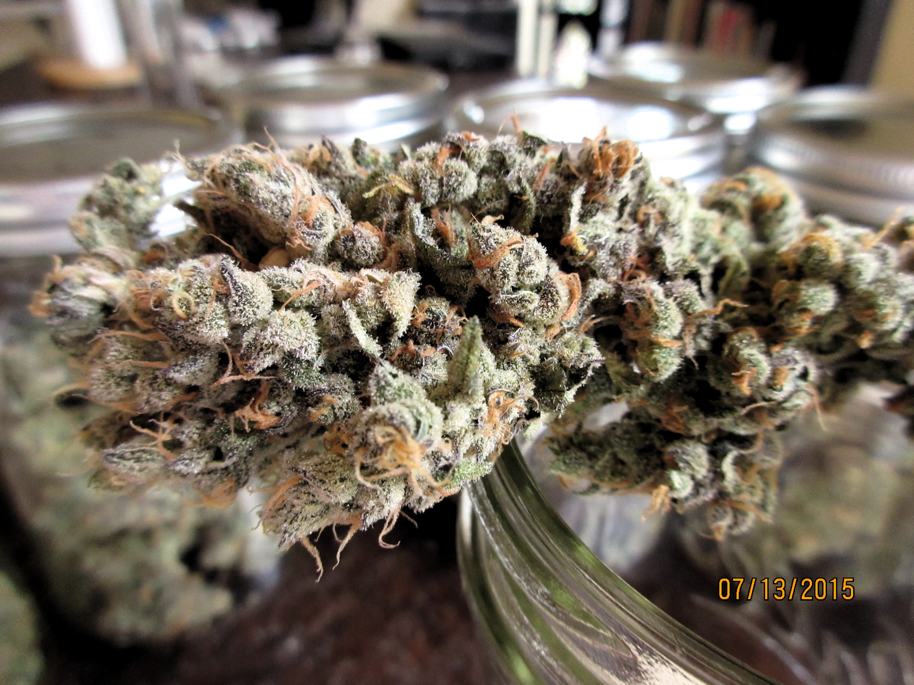
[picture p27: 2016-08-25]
weed/pics/EG2.5.JPG

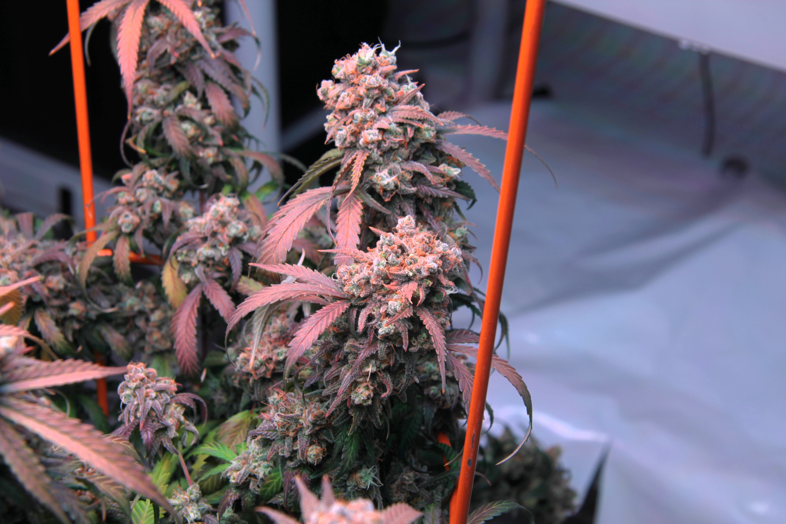
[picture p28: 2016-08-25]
weed/pics/TW.1.JPG

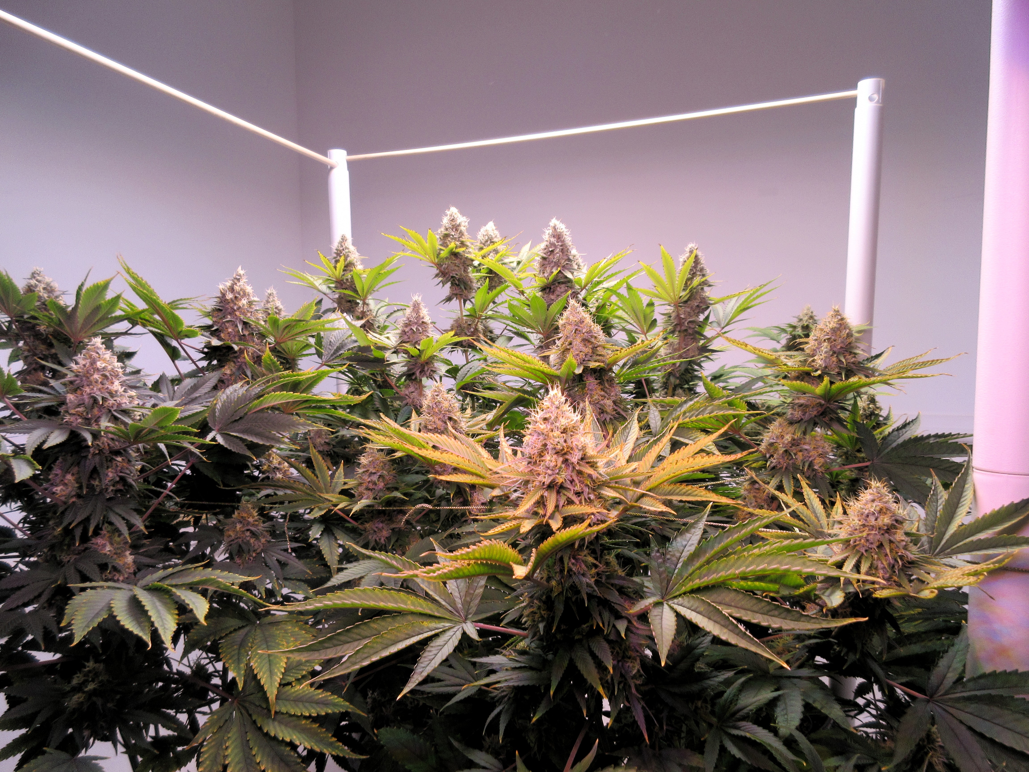
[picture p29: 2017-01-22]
weed/pics/ak48-0.JPG

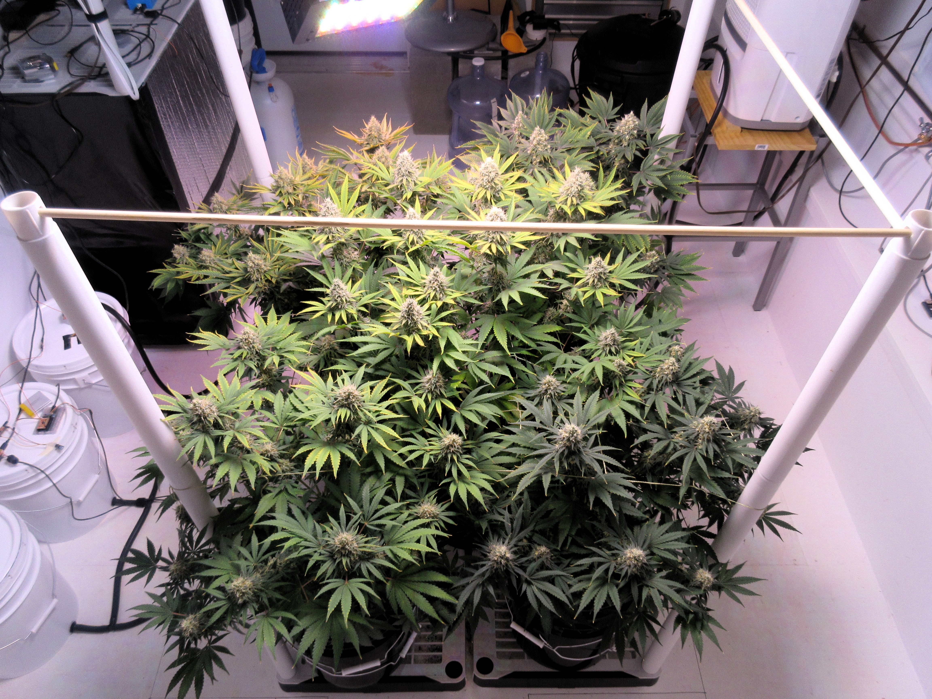
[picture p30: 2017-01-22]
weed/pics/ak48-1.JPG

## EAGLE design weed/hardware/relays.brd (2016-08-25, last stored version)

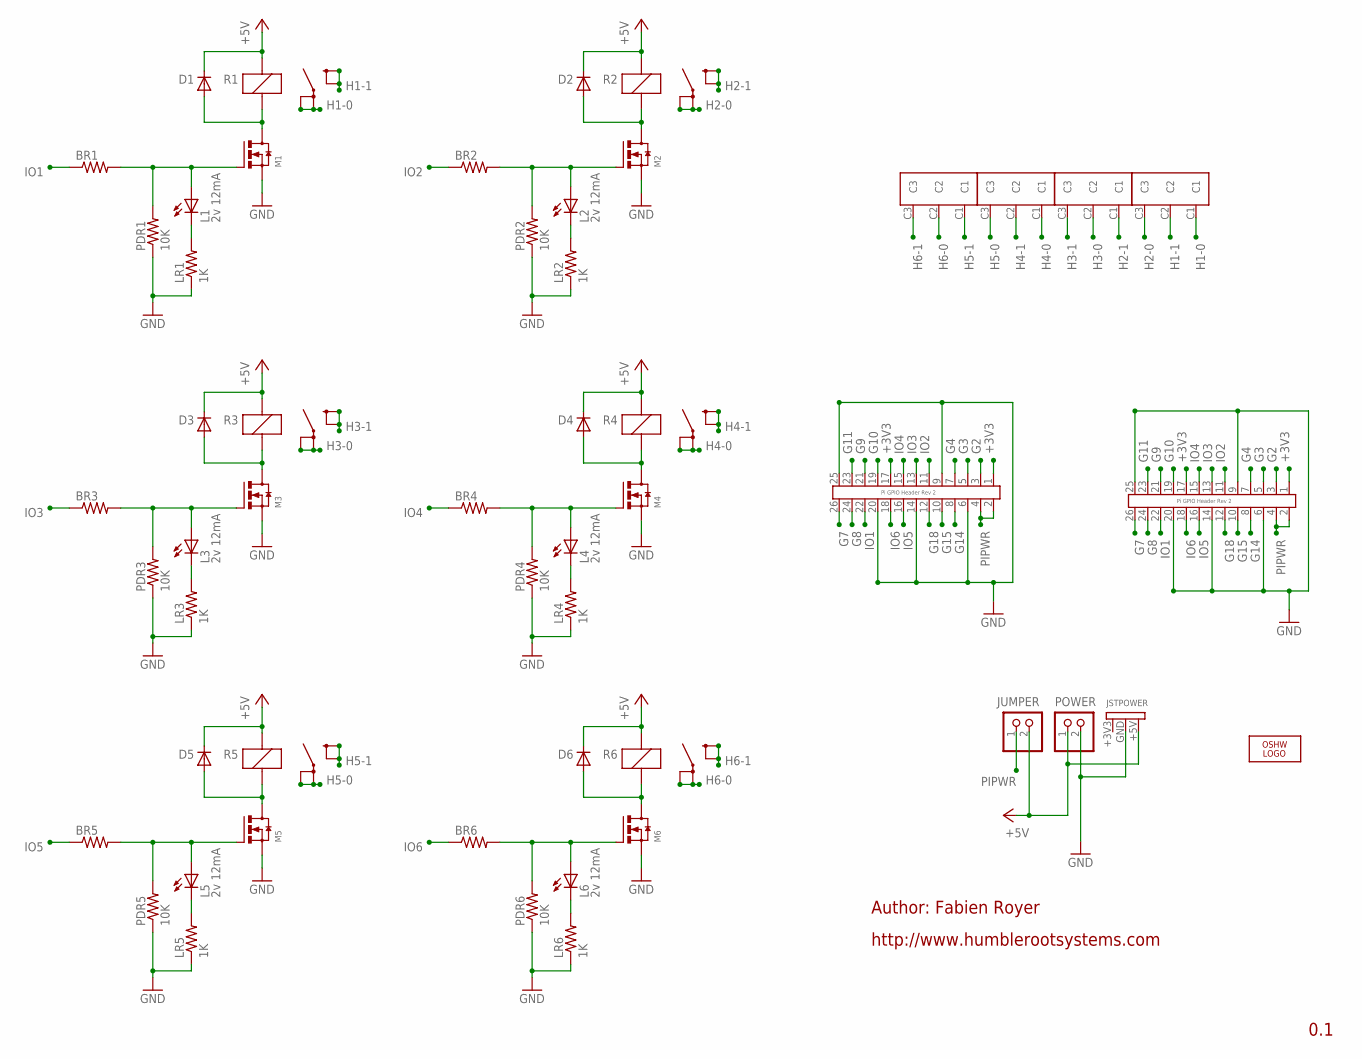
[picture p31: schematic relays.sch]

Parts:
BR1, BR2, BR3, BR4, BR5, BR6: R-US_0207/10; 0207/10
D1, D2, D3, D4, D5, D6: 1N4004; DO41-10
JSTPOWER: JST_PH_3_POSITIONS_TOP_ENTRY_THROUGH_HOLE
JUMPER: 5V; 1X02
L1, L2, L3, L4, L5, L6: 2v 12mA; LED3MM
LOGO1: OSHW_LOGO_6MILX0200-NT; OSHW_6X200_NOTEXT
LR1, LR2, LR3, LR4, LR5, LR6: 1K; 0207/10
M1, M2, M3, M4, M5, M6: FAIRCHILD_2N700X_N-CHANNEL_MOSFET_TO92; FAIRCHILD_2N700X_TO92
PDR1, PDR2, PDR3, PDR4, PDR5, PDR6: 10K; 0207/10
POWER: 5V; 1X02
R1, R2, R3, R4, R5, R6: SCHRACK_POWER_PCB_RELAY_RZ_16A_NO; SCHRACK_POWER_PCB_RELAY_RZ_16A
U$5, U$6: PI_GPIO_13X2_PIN_HEADER; PIN_HEADER_13X2_POSITIONS_DIL
WC1, WC2, WC3, WC4: PHOENIX_WIRE_CONTACT_3_POSITIONS_GENERIC

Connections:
+3V3: U$5.1 (P1_3V3), U$5.17 (P17_3V3), U$6.1 (P1_3V3), U$6.17 (P17_3V3)
+5V: D1.C, D2.C, D3.C, D4.C, D5.C, D6.C, JSTPOWER.+5V, JUMPER.2, POWER.1, R1.COIL_A1, R2.COIL_A1, R3.COIL_A1, R4.COIL_A1, R5.COIL_A1, R6.COIL_A1
G2: U$5.3 (P3_GPIO2_SDA), U$6.3 (P3_GPIO2_SDA)
G3: U$5.5 (P5_GPIO3_SCL), U$6.5 (P5_GPIO3_SCL)
G4: U$5.7 (P7_GPIO4), U$6.7 (P7_GPIO4)
G7: U$5.26 (P26_GPIO7_SPI0_CE1), U$6.26 (P26_GPIO7_SPI0_CE1)
G8: U$5.24 (P24_GPIO8_SPI0_CE0), U$6.24 (P24_GPIO8_SPI0_CE0)
G9: U$5.21 (P21_GPIO9_SPI0_MISO), U$6.21 (P21_GPIO9_SPI0_MISO)
G10: U$5.19 (P19_GPIO10_SPI0_MOSI), U$6.19 (P19_GPIO10_SPI0_MOSI)
G11: U$5.23 (P23_GPIO11_SPI0_SCLK), U$6.23 (P23_GPIO11_SPI0_SCLK)
G14: U$5.8 (P8_GPIO14_UART0_TXD), U$6.8 (P8_GPIO14_UART0_TXD)
G15: U$5.10 (P10_GPIO15_UART0_RXD), U$6.10 (P10_GPIO15_UART0_RXD)
G18: U$5.12 (P12_GPIO18), U$6.12 (P12_GPIO18)
GND: JSTPOWER.GND, LR1.1, LR2.1, LR3.1, LR4.1, LR5.1, LR6.1, M1.S (SOURCE), M2.S (SOURCE), M3.S (SOURCE), M4.S (SOURCE), M5.S (SOURCE), M6.S (SOURCE), PDR1.1, PDR2.1, PDR3.1, PDR4.1, PDR5.1, PDR6.1, POWER.2, U$5.6 (P6_GND), U$5.9 (P9_GND), U$5.14 (P14_GND), U$5.20 (P20_GND), U$5.25 (P25_GND), U$6.6 (P6_GND), U$6.9 (P9_GND), U$6.14 (P14_GND), U$6.20 (P20_GND), U$6.25 (P25_GND)
H1-0: R1.11A_LOAD, R1.11B_LOAD, WC1.C1
H1-1: R1.14A_LOAD, R1.14B_LOAD, WC1.C2
H2-0: R2.11A_LOAD, R2.11B_LOAD, WC1.C3
H2-1: R2.14A_LOAD, R2.14B_LOAD, WC2.C1
H3-0: R3.11A_LOAD, R3.11B_LOAD, WC2.C2
H3-1: R3.14A_LOAD, R3.14B_LOAD, WC2.C3
H4-0: R4.11A_LOAD, R4.11B_LOAD, WC3.C1
H4-1: R4.14A_LOAD, R4.14B_LOAD, WC3.C2
H5-0: R5.11A_LOAD, R5.11B_LOAD, WC3.C3
H5-1: R5.14A_LOAD, R5.14B_LOAD, WC4.C1
H6-0: R6.11A_LOAD, R6.11B_LOAD, WC4.C2
H6-1: R6.14A_LOAD, R6.14B_LOAD, WC4.C3
IO1: BR1.1, U$5.22 (P22_GPIO25), U$6.22 (P22_GPIO25)
IO2: BR2.1, U$5.11 (P11_GPIO17), U$6.11 (P11_GPIO17)
IO3: BR3.1, U$5.13 (P13_GPIO27), U$6.13 (P13_GPIO27)
IO4: BR4.1, U$5.15 (P15_GPIO22), U$6.15 (P15_GPIO22)
IO5: BR5.1, U$5.16 (P16_GPIO23), U$6.16 (P16_GPIO23)
IO6: BR6.1, U$5.18 (P18_GPIO24), U$6.18 (P18_GPIO24)
unnamed: L1.K (C), LR1.2
unnamed: BR2.2, L2.A, M2.G (GATE), PDR2.2
unnamed: L2.K (C), LR2.2
unnamed: D1.A, M1.D (DRAIN), R1.COIL_A2
unnamed: D2.A, M2.D (DRAIN), R2.COIL_A2
unnamed: BR1.2, L1.A, M1.G (GATE), PDR1.2
unnamed: BR3.2, L3.A, M3.G (GATE), PDR3.2
unnamed: L3.K (C), LR3.2
unnamed: D3.A, M3.D (DRAIN), R3.COIL_A2
unnamed: BR4.2, L4.A, M4.G (GATE), PDR4.2
unnamed: L4.K (C), LR4.2
unnamed: D4.A, M4.D (DRAIN), R4.COIL_A2
unnamed: BR5.2, L5.A, M5.G (GATE), PDR5.2
unnamed: L5.K (C), LR5.2
unnamed: D5.A, M5.D (DRAIN), R5.COIL_A2
unnamed: BR6.2, L6.A, M6.G (GATE), PDR6.2
unnamed: L6.K (C), LR6.2
unnamed: D6.A, M6.D (DRAIN), R6.COIL_A2
PIPWR: JUMPER.1, U$5.2 (P2_5V), U$5.4 (P4_5V), U$6.2 (P2_5V), U$6.4 (P4_5V)

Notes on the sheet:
0.1
Author: Fabien Royer
http://www.humblerootsystems.com

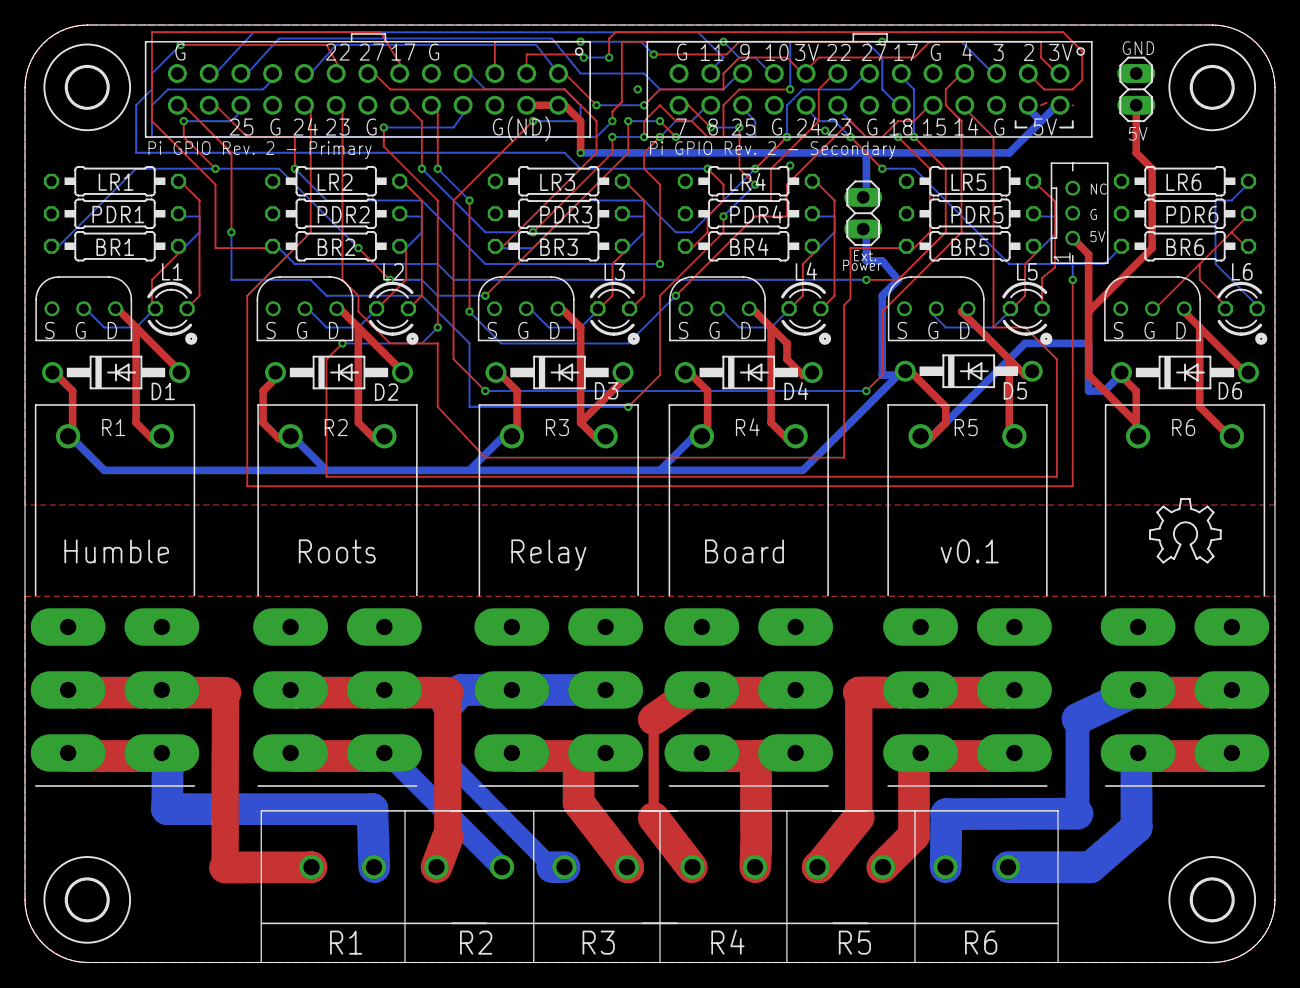
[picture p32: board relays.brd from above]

Board: 2 copper layers, 100.0 x 75.0 mm, 56 parts (0 on the bottom side), 51 nets.

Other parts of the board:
U$1, U$2, U$3, U$4: 3,2

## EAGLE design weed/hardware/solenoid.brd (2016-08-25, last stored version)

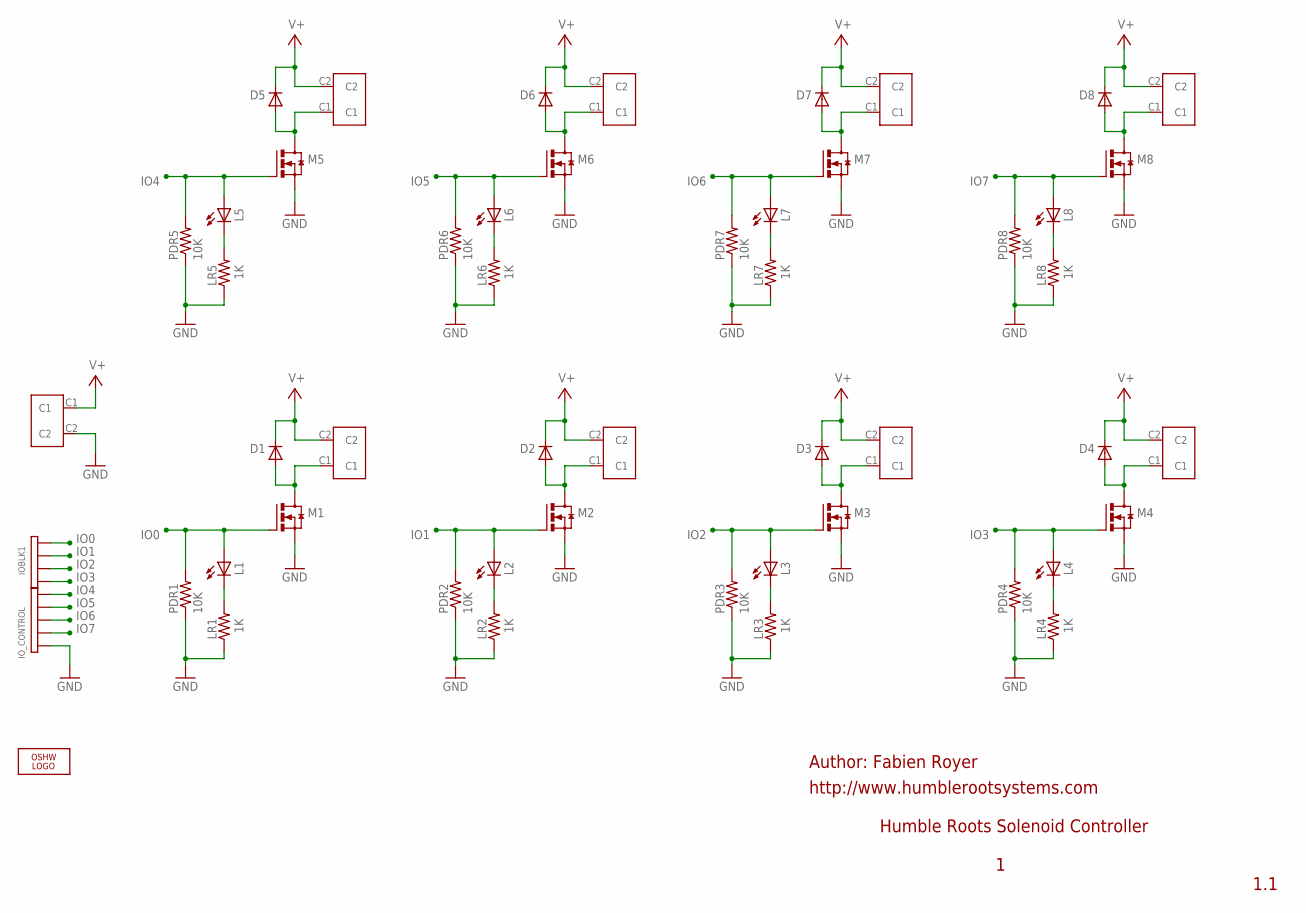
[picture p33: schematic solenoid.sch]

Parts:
D1, D2, D3, D4, D5, D6, D7, D8: 1N4004; DO41-10
IOBLK1: PIN_HEADER_4_POSITIONS
IO_CONTROL: PIN_HEADER_5_POSITIONS
L1, L2, L3, L4, L5, L6, L7, L8: 2v 12mA; LED3MM
LOGO1: OSHW_LOGO_6MILX0200-NT; OSHW_6X200_NOTEXT
LR1, LR2, LR3, LR4, LR5, LR6, LR7, LR8: 1K; 0207/10
M1, M2, M3, M4, M5, M6, M7, M8: INTERNATIONAL_RECTIFIER_IRLB8721PBF; TO220ABS
PDR1, PDR2, PDR3, PDR4, PDR5, PDR6, PDR7, PDR8: 10K; 0207/10
POWER: PHOENIX_WIRE_CONTACT_2_POSITIONS_GENERIC
V1, V2, V3, V4, V5, V6, V7, V8: PHOENIX_WIRE_CONTACT_2_POSITIONS_GENERIC

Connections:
GND: IO_CONTROL.5, LR1.1, LR2.1, LR3.1, LR4.1, LR5.1, LR6.1, LR7.1, LR8.1, M1.3 (SOURCE), M2.3 (SOURCE), M3.3 (SOURCE), M4.3 (SOURCE), M5.3 (SOURCE), M6.3 (SOURCE), M7.3 (SOURCE), M8.3 (SOURCE), PDR1.1, PDR2.1, PDR3.1, PDR4.1, PDR5.1, PDR6.1, PDR7.1, PDR8.1, POWER.C2
IO0: IOBLK1.1, L1.A, M1.1 (GATE), PDR1.2
IO1: IOBLK1.2, L2.A, M2.1 (GATE), PDR2.2
IO2: IOBLK1.3, L3.A, M3.1 (GATE), PDR3.2
IO3: IOBLK1.4, L4.A, M4.1 (GATE), PDR4.2
IO4: IO_CONTROL.1, L5.A, M5.1 (GATE), PDR5.2
IO5: IO_CONTROL.2, L6.A, M6.1 (GATE), PDR6.2
IO6: IO_CONTROL.3, L7.A, M7.1 (GATE), PDR7.2
IO7: IO_CONTROL.4, L8.A, M8.1 (GATE), PDR8.2
unnamed: L1.K (C), LR1.2
unnamed: L2.K (C), LR2.2
unnamed: D2.A, M2.2 (DRAIN), V2.C1
unnamed: L3.K (C), LR3.2
unnamed: D1.A, M1.2 (DRAIN), V1.C1
unnamed: D3.A, M3.2 (DRAIN), V3.C1
unnamed: L4.K (C), LR4.2
unnamed: D4.A, M4.2 (DRAIN), V4.C1
unnamed: L5.K (C), LR5.2
unnamed: D5.A, M5.2 (DRAIN), V5.C1
unnamed: L6.K (C), LR6.2
unnamed: D6.A, M6.2 (DRAIN), V6.C1
unnamed: L7.K (C), LR7.2
unnamed: D7.A, M7.2 (DRAIN), V7.C1
unnamed: L8.K (C), LR8.2
unnamed: D8.A, M8.2 (DRAIN), V8.C1
V+: D1.C, D2.C, D3.C, D4.C, D5.C, D6.C, D7.C, D8.C, POWER.C1, V1.C2, V2.C2, V3.C2, V4.C2, V5.C2, V6.C2, V7.C2, V8.C2

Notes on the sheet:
Humble Roots Solenoid Controller
1.1
Author: Fabien Royer
http://www.humblerootsystems.com

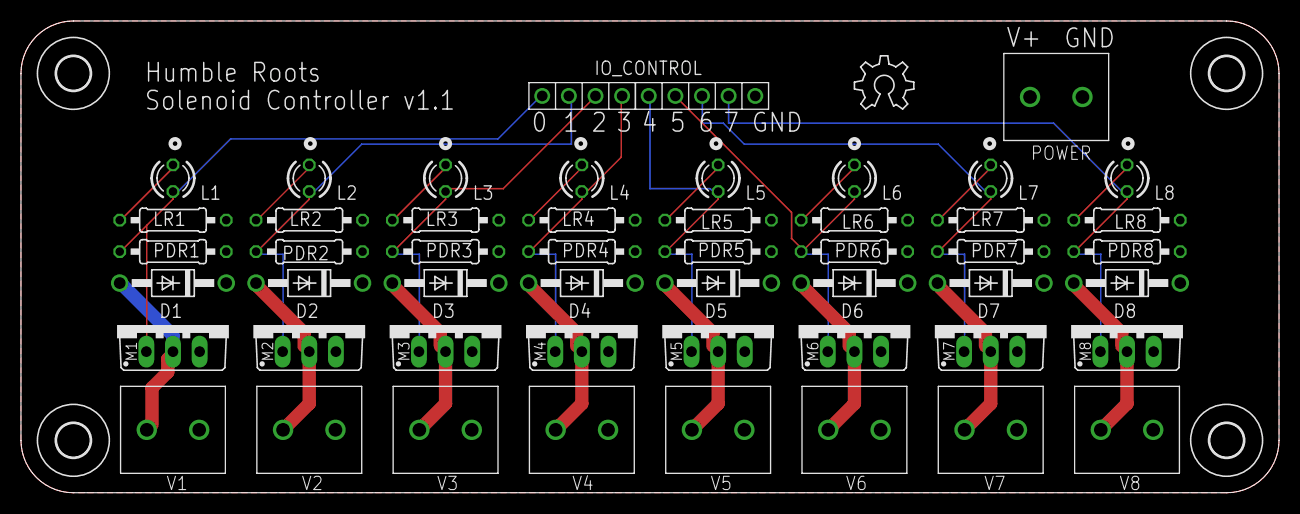
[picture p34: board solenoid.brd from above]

Board: 2 copper layers, 120.0 x 45.0 mm, 56 parts (0 on the bottom side), 26 nets.

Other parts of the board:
U$1, U$2, U$3, U$4: 3,2

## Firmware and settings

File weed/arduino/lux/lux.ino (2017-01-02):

/*
    Author: Fabien Royer
    Copyright 2013-2016 Fabien Royer

    This file is part of the "Humble Roots Project" or "HRP".

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
    You should have received a copy of the GNU General Public License
    along with "HRP".  If not, see <http://www.gnu.org/licenses/>.
*/

#include <PString.h>
#include <LowPower.h>
#include <RFM69.h>

#define LOW_BATTERY_THRESHOLD    3.0
#define EXTERNAL_POWER_VOLTAGE   5.0
#define SERIAL_BAUD              115200
#define NETWORK_ID               100
#define GATEWAY_ID               1
#define THIS_NODE_ID             70
#define FREQUENCY                RF69_433MHZ
#define BAT_VOLTAGE              A7
#define LUX_MAX_SAMPLES          10
#define POWER_DOWN_SECS          60

// GA1A12S202 Log-scale Analog Light Sensor - https://www.adafruit.com/products/1384
#define LUX_SENSOR A0
#define ADC_RANGE  float(1024)   // 3.3v
#define LOG_RANGE  float(5.0)    // 3.3v = 10^5 lux

RFM69 radio;
char Buffer[100];
byte CryptoKey[] = "<YourCryptoKey!>";
PString str(Buffer, sizeof(Buffer));

void setup() {
  Serial.begin(SERIAL_BAUD);
  radio.initialize(FREQUENCY, THIS_NODE_ID, NETWORK_ID);
  radio.encrypt((const char*)CryptoKey);
  pinMode(LUX_SENSOR, INPUT);
  pinMode(BAT_VOLTAGE, INPUT);
  Serial.println("Humble Roots Lux Meter ready");
  Serial.flush();
}

void loop() {
  SendData();
  radio.sleep();
  PowerDown(POWER_DOWN_SECS);
}

void PowerDown(int seconds){
  while (--seconds > 0) {
    LowPower.powerDown(SLEEP_1S, ADC_OFF, BOD_OFF);
  }
}

float GetVBat() {
  // actual input voltage = analogRead(A7) * 0.00322 (3.3v/1024) * 1.47 (10k+4.7k voltage divider ratio)
  return analogRead(BAT_VOLTAGE) * 0.00322 * 1.47;
}

float GetLux(int samples) {
  float raw = 0;
  int count = samples;
  while(count--) {
    raw += analogRead(LUX_SENSOR);
    delay(2);
  }
  return RawToLux(raw / samples);
}

float RawToLux(int raw) {
  return pow(10, (raw * LOG_RANGE) / ADC_RANGE);
}

void SendData() {
  float vBat = GetVBat();
  str.begin();
  str.print("t=lux&bat=");
  str.print(vBat);
  str.print("&low=");
  str.print((vBat <= LOW_BATTERY_THRESHOLD) ? 1:0);
  str.print("&pwr=");
  str.print((vBat > EXTERNAL_POWER_VOLTAGE) ? 1:0);
  str.print("&lux=");
  str.print(GetLux(LUX_MAX_SAMPLES));

  Serial.print("TX: ");
  Serial.print(Buffer);
  Serial.print(" (");
  Serial.print(str.length());
  Serial.print(")");

  if (radio.sendWithRetry(GATEWAY_ID, Buffer, str.length())) {
    Serial.println(":ACK");
  } else {
    Serial.println(":NAK");
  }

  Serial.flush();
}

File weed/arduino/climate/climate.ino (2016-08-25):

/*
    Author: Fabien Royer
    Copyright 2013-2015 Fabien Royer

    This file is part of the "Humble Roots Project" or "HRP".

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
    You should have received a copy of the GNU General Public License
    along with "HRP".  If not, see <http://www.gnu.org/licenses/>.
*/
#include <Wire.h>
#include <SI7021.h>
#include <SFE_BMP180.h>
#include <SPI.h>
#include <RFM69.h>
#include <LowPower.h>
#include <PString.h>
#include <EEPROMex.h>
#include <EEPROMVar.h>

#define LOW_BATTERY_THRESHOLD    3.5
#define EXTERNAL_POWER_VOLTAGE   4.3
#define SERIAL_BAUD              115200
#define NETWORK_ID               100
#define GATEWAY_ID               1
#define THIS_NODE_ID             40
#define FREQUENCY                RF69_433MHZ
#define BAT_VOLTAGE_MOSFET       A3
#define BAT_VOLTAGE              A7
#define MAGIC                    31415
#define POWER_DOWN_SECS          60

RFM69 radio;
SI7021 sensor;
SFE_BMP180 pressure;
char Buffer[100];
byte CryptoKey[] = "<YourCryptoKey!>";
PString str(Buffer, sizeof(Buffer));
int MagicAddr = EEPROM.getAddress(sizeof(int));
int CryptoKeyAddr = EEPROM.getAddress(sizeof(CryptoKey));

void setup() {
  Serial.begin(SERIAL_BAUD);
  InitConfig();
  delay(10);
  radio.initialize(FREQUENCY, THIS_NODE_ID, NETWORK_ID);
  radio.encrypt((const char*)CryptoKey);
  sensor.begin();
  if (pressure.begin()) {
    Serial.println("BMP180 init OK");
  } else {
    Serial.println("BMP180 init failed");
  }
  Serial.println("Ready");
  Serial.flush();
}

void InitConfig() {
  if (EEPROM.readInt(MagicAddr) != MAGIC) {
    EEPROM.writeBlock<byte>(CryptoKeyAddr, CryptoKey, sizeof(CryptoKey));
    EEPROM.writeInt(MagicAddr, MAGIC);
    Serial.println("EE init.");
  }
  EEPROM.readBlock<byte>(CryptoKeyAddr, CryptoKey, sizeof(CryptoKey));
  Serial.print("Key: ");
  Serial.println((const char*)CryptoKey);
  Serial.flush();
}

float GetVBat() {
  //turn MOSFET ON and read voltage, should give a valid reading
  pinMode(BAT_VOLTAGE_MOSFET, OUTPUT);
  digitalWrite(BAT_VOLTAGE_MOSFET, LOW);
  float vbat = analogRead(BAT_VOLTAGE)/100.00;
  //put A3 in HI-Z mode (to allow mosfet gate pullup to turn it OFF)
  pinMode(BAT_VOLTAGE_MOSFET, INPUT);
  return vbat;
}

float GetTemp() {
  return float(sensor.getCelsiusHundredths()/100.00);
}

int GetRH() {
  return sensor.getHumidityPercent();
}

void loop() {
  SendData();
  Serial.flush();
  radio.sleep();
  PowerDown(POWER_DOWN_SECS);
}

void PowerDown(int seconds){
  while (--seconds > 0) {
    LowPower.powerDown(SLEEP_1S, ADC_OFF, BOD_OFF);
  }
}

void SendData() {
  float vBat = GetVBat();
  str.begin();
  str.print("t=clm&bat=");
  str.print(vBat);
  str.print("&low=");
  str.print((vBat <= LOW_BATTERY_THRESHOLD) ? 1:0);
  str.print("&pwr=");
  str.print((vBat > EXTERNAL_POWER_VOLTAGE) ? 1:0);
  str.print("&tmp=");
  str.print(GetTemp());
  str.print("&rh=");
  str.print(GetRH());

  Serial.print("TX: ");
  Serial.print(Buffer);
  Serial.print(" (");
  Serial.print(str.length());
  Serial.print(")");

  if (radio.sendWithRetry(GATEWAY_ID, Buffer, str.length()))
    Serial.println(":ACK");
  else
    Serial.println(":NACK");
}

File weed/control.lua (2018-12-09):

local log = require("log")
_ENV.log = log

local gateway = require("gateway")
local config = require("config")
local db = require("influxdb")
local rules = require("rules")
local replay = require("replay")
local heartbeat = require("heartbeat")
local sms = require("sms")
local report = require("report")
local listen = require("listener")
local shell = require("shell")
local logo = require("logo")

local listening = false
local manualMode = false

local cfgFilePath = "./config/config.toml"
local cfg = config.getConfig(cfgFilePath)

local function writeEventToDB(level, msg, info)
  if cfg.influxDB.enabled then
    db.pushEvent("event", level, info.short_src, msg)
    if cfg.influxDB.udp.enabled then
      db.postUDP(cfg.influxDB.host, cfg.influxDB.udp.events)
    else
      db.post(cfg.influxDB.host, cfg.influxDB.port, cfg.influxDB.events)
    end
  end
end

local function writeMsgToDB(msgResolved, valueId)
  if cfg.influxDB.enabled then
    if cfg.fixup[valueId] ~= nil then
      local values = cfg.fixup[valueId]
      local fixedValue = values[msgResolved[valueId]]
      msgResolved[valueId] = fixedValue
    end
    db.push(msgResolved, valueId)
    if cfg.influxDB.udp.enabled then
      db.postUDP(cfg.influxDB.host, cfg.influxDB.udp.sensors)
    else
      db.post(cfg.influxDB.host, cfg.influxDB.port, cfg.influxDB.db)
    end
  end
end

local function writeSingleValueToDB(measurement, tag, value)
  if cfg.influxDB.enabled then
    db.pushSingleValue(measurement, tag, value)
    if cfg.influxDB.udp.enabled then
      db.postUDP(cfg.influxDB.host, cfg.influxDB.udp.sensors)
    else
      db.post(cfg.influxDB.host, cfg.influxDB.port, cfg.influxDB.db)
    end
  end
end

local function onData(data)
  log.trace(string.format("Packet: %s", data))
  
  if not cfg.serial.enabled and not cfg.replay.enabled then
    log.debug(string.format("Ignoring: %s", data))
    return
  end
  
  if not listening and data == "Listening" then
    log.info(data)
    listening = true
    return
  end
  
  if cfg.replay.record then
    replay.record(data)
  end
  
  local msg = rules.decode(data)
  local msgResolved = rules.resolve(msg, cfg)
  if msg.node ~= nil and msg.tx == nil and msg.t ~= nil and msgResolved.node ~= nil then
    -- sensor data was received...
    heartbeat.pulse(msgResolved.node)
    
    local _rulesNode = cfg.control[msgResolved.node]
    if _rulesNode == nil then
      log.warn(string.format("Config out of sync! Invalid node %s referenced in packet: %s", msg.node, data))
      return
    end
    
    local _rules = _rulesNode[msgResolved.t]
    if _rules == nil then
      log.warn(string.format("Config out of sync! Invalid type %s referenced in packet: %s", msg.t, data))
      return
    end

    local anyCommandSent = false
    
    if _rules ~= nil then
      local ruleIndex = 0
      local commandSent = false
      local lastValueName = ""
      local valueNameChanged = false
      
      while true do
        local rule = cfg.control[msgResolved.node][msgResolved.t][tostring(ruleIndex)]

        if rule == nil then
          break
        end
        
        rule.node = msgResolved.node

        if lastValueName ~= rule.value then
          lastValueName = rule.value
          valueNameChanged = true
          commandSent = false
        else
          valueNameChanged = false
        end

        if rule.cmd ~= nil then
          if not valueNameChanged and commandSent then
            log.info(string.format("Command already fired. Skipping default rule action: %s.%s.%s", msgResolved.node, msgResolved.t, ruleIndex))
            goto next
          end
        end
        
        log.info(string.format("Sensor rule: %s.%s.%s", msgResolved.node, msgResolved.t, ruleIndex))
        
        if not manualMode and rules.eval(rule, msgResolved, gateway, cfg) then
          commandSent = true
          anyCommandSent = true
        end

      ::next::
        if valueNameChanged then
          if msgResolved.actualValue ~= nil and rule.state == nil then
            writeMsgToDB(msgResolved, rule.value)
            report.update(msgResolved.node, rule.value, msgResolved.actualValue)
          elseif rule.state ~= nil then
            writeMsgToDB(msgResolved, rule.state)
            report.update(msgResolved.node, msgResolved[rule.value], rule.value, rule.state, msgResolved[rule.state])
          end
        end
      
        ruleIndex = ruleIndex + 1
      end

      if not manualMode and not anyCommandSent and _rules.cmd ~= nil then
        log.trace(string.format("Executing default action for %s.%s: %s", msgResolved.node, msgResolved.t, _rules.cmd))
        rules.sendCommand(_rules.cmd, gateway, cfg)
      end
    end

    if cfg.control.signal ~= nil then
      local rule = cfg.control.signal
      rule.node = msgResolved.node
      log.info(string.format("Signal rule: %s.%s", msgResolved.node, rule.value))
      rules.eval(rule, msgResolved, gateway, cfg)
      writeMsgToDB(msgResolved, rule.value)
    end

  elseif msg.node ~= nil and msg.tx ~= nil and msg.t == nil then
    -- a command ack/nak was received...
    gateway.retry(msg)
    writeSingleValueToDB("tx", msgResolved.node, msgResolved.tx)
  else
    log.warn(string.format("Discarded: %s", data))
  end
end

local function onShellMsg(line)
  line = string.lower(line)
  log.warn(string.format("Shell command: %s", line))
  local opts = shell.parse(line)
  if opts.q ~= nil and opts.q == "report" then
    return report.report(cfg)
  elseif opts.w ~= nil then
    local _, wOpt = string.find(line, "-w")
    if wOpt ~= nil and #line > (wOpt + 2) then
      log.log(string.sub(line, wOpt + 2))
    end
  elseif opts.m ~= nil then
    if opts.m == "manual" then
      manualMode = true
    else
      manualMode = false
    end
    log.warn(string.format("Switched to '%s' mode", opts.m))
  elseif opts.n ~= nil and opts.s ~= nil and (opts.r ~= nil or opts.v ~= nil) then
    local cmdFinal = rules.sendCommand(line, gateway, cfg)
    if cmdFinal ~= nil then
      log.warn(string.format("Sent shell command: %s", cmdFinal))
    else
      local err = string.format("Bad param(s) / duplicate command: %s, cmdFinal: %s", line, cmdFinal)
      log.error(err)
      return err
    end
  else
    local err = string.format("Invalid shell command: %s", line)
    log.error(err)
    return err
  end
  return "ok"
end

local function onSmsMsg(from, body)
  local _ = from
  local reply = onShellMsg(body)
  if reply ~= nil then
    sms.send(cfg, reply)
  end
end

local function getNextTime()
  return os.time() + cfg.control.tick.freqSec
end

local nextTime = getNextTime()
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

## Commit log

2016-08-25 compressed into hardware.zip
    [relays.brd, relays.sch, solenoid.brd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]
2016-08-25 compressed hardware designs and case
2016-08-27 fix to enalbe data replay
    [control.lua]
2016-10-10 fix sensor <-> rule mismatch
2016-10-23 device command cleanup
2016-10-23 fix detect restart on config change in replay mode
    [control.lua]
2016-10-24 fix default rule firing for invalid sensor
    still need to handle mixed nodes of same type bug.
2016-11-28 refactor of json config and rule processing
    Enables multiple rules & optional default rule per sensor
2016-12-04 fix timer rules schema
2016-12-04 fix timer rules processing, gateway reset in replay mode
    [control.lua]
2016-12-07 fix handling of "default" command rule
    [control.lua]
2016-12-10 fix gateway startup / shutdown log level
    [control.lua]
2016-12-10 fix trace
2016-12-25 add light power monitoring (lux) node
2017-01-02 add lux meter arduino sketch
2017-01-12 fix reset all alerts on gateway restart
    [control.lua]
2017-01-15 add influxdb udp transport support
    Ensures that http calls to the db won't hang and disrupt operations when
    the target influxdb is inaccessible.
    [control.lua]
2017-01-17 add init/shutdown functions handling UDP socket creation/destruction
2017-01-22 add InfluxDB snapshot with sensor & event data
2017-11-27 switch from .json to .toml config
2017-11-27 Refactor to support new rule format and indexing. Fixed shell input handling. Removed unnecessary tostring() calls.
    [control.lua]
2017-11-27 add self-contained SMS gateway
    Tested with Huawei BOLTZ 4G LTE modem
2017-11-27 Refactored according to new rule format. Fix 'all-day / 00:00-23:59' timing hole. Removed md5 dependency. Removed unnecessary tostring() calls.
2017-11-27 Fix report show index instead of name with relays/valves
2017-11-27 add AK-48 grow journal
    [ak48.csv]
2018-02-04 add handling of default rules within rule blocks
    [control.climate.clm]
    [control.climate.clm.0]
    enabled = true
    value = "tmp"
    time = {from = "17:00", to = "05:00"}
    on = {op = ">=", setpoint = 23.0, cmd = "-n relay -r vent -s on"}
    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
2018-11-23 updated to used compound rules
    add calibration offset
2018-11-23 use .toml config files
    fix for compound rules
    remove reset between shell commands
    [control.lua]
2018-11-23 remove md5 dependency
    fix time gap between 23:59 and 00:00
    remove unnecessary tostring() calls
    ignore duplicate commands
    handle compound rules
    add sensor calibration offset
2018-12-09 fix detect and log out of sync configuration
    [control.lua]

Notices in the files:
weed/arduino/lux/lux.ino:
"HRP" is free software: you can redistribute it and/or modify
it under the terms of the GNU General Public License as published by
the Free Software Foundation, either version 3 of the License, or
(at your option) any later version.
